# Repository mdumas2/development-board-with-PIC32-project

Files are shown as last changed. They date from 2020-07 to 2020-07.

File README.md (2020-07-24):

# PCB project of our development board utilizing PIC32
***
## SCHEMATICS
schematic
## 2D
PCB 2D
## 3D
PCB 3D
## ISSUES
issues
# Code of our development board utilizing PIC32
***
## STATE MACHINE
Maquina de estado
## UML DIAGRAM
UML
## Bluetooth App
app
## VS code App
pc program

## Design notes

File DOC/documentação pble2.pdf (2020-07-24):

## PBLE02 - Aprendizagem baseada em projeto

Documentação Final

Guilherme F. da Silva 2017011836

Mateus Dumas Lima 2017017965

Windson Faria Maia 33213

Itajubá
2019

Sumário

### 1. Introdução

Este projeto faz parte do conteúdo da disciplina PBLE02 (Aprendizagem Baseada em Projetos 2) do curso de Engenharia Eletrônica da UNIFEI (Universidade Federal de Itajubá) e tem por objetivo dar sequência a disciplina PBLE01 que tem por objetivo apresentar o desenvolvimento de produto desde a concepção até a fabricação.

Nessa etapa através da troca de projetos permite um conhecimento de forma pratica de desenvolvimento de produto.

### 2. Projeto

Em PBLE01 o projeto de hardware tinha características gerais:

Item | Descrição
Conector de alimentação | PJ-002A
Tensão de alimentação | 7Vcc a 12Vcc
Microcontrolador | PIC32MM0064GPM048-I/PT
Conversor USB-Serial | FT232RL / MCP2200-I/SO
Reguladores de 3.3V | LD1117S33CTR
Reguladores de 5.0V | LD1117DT50TR
Amplificador operacional | LM358DG
Cristal de 12 MHz | ATS12A
Diodo retificador Schottky | 1N5819HW-7
Conectores USB | 897-43-004-90-000000
Memória E2PROM- | 24LC512-I/SM
Cristal de 32.768 kHz (RTC) | AB38T-32.768KHZ

Tabela 1 - Características gerais do hardware

Com objetivo de trazer os alunos em um ambiente real de desenvolvimento, em PBLE02 os projetos foram trocados de forma aleatória, trazendo um novo desafio e estudar mais a fundo o projeto já feito na disciplina anterior. Recebemos o projeto da equipe 01, as características gerais de ambas as placas é semelhante, salvo algumas diferenças individuais que não interferem na realização do objetivo para o qual foram projetadas. Seguem nos próximos tópicos os detalhes de cada subcircuito deste projeto, juntamente com os pré-requisitos de cada um deles.

### 2.1 Alimentação

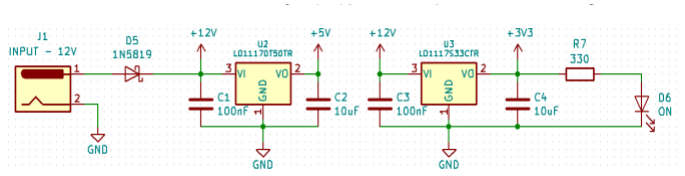
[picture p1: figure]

Figura 1 subcircuito de alimentação

O grupo optou por utilizar os reguladores em paralelo, a fim de evitar que a corrente consumida pelo regulador de 3,3V não afetasse o de 5V. O circuito também possui um diodo schottky de proteção para evitar corrente reversa, assim como um LED de sinalização (D6) para avisar quando a PCI estiver ligada.

### 2.2 Microcontrolador

Como | requisito, | foi | empregado | o | PIC32MM0064GPM048-I/PT. | Tal
microprocessador deve operar com clock interno, possuir quatro diodos emissores de luz para sinalizações diversas e botão de reinício por meio de uma chave táctil de quatro terminais e do tipo normalmente aberta. O reset da placa foi feito para operar por uma chave táctil de quatro terminais. O debounce feito por software.

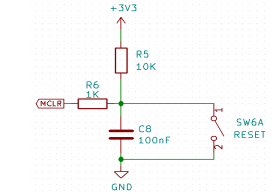
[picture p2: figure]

Figura 2 Circuito de reset.

Figura 3 Subcircuito do microcontrolador

### 2.2 Comunicação

Foi empregado um conversor USB-serial devidamente integrado ao periférico de comunicação UART do microcontrolador com configuração autoalimentada. Para tanto, foi implementado dois tipos de conversores, FT232 e MCP2200-I/SO, de modo que apenas um é ativado para efetuar a comunicação.

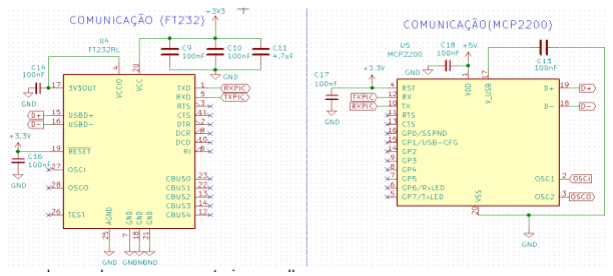
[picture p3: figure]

Figura 5 – Conversores USB-serial

Além disso, utilizou-se 2 conectores USB, no qual o primeiro se conectaria diretamente ao micro utilizando sua comunicação nativa, enquanto o outro seguiria em paralelo tanto para o FT232 quanto para o MCP2200.

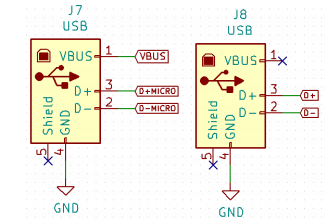
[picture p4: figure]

Figura 6 Conectores USB.

### 2.3 Comunicação

Um dos periféricos implementado é o display LCD 16x2, modelo JHD162A, conectado a uma barra de conexão.

Figura 7 Display LCD

A placa possui um teclado de cinco teclas desenvolvido por meio de chaves tácteis de quatro terminais cada, sendo lido através de uma estrutura de divisor resistivo numa entrada analógica.

Figura 8 Teclado com entrada analógica.

Para a programação do microcontrolador por meio do ICSP, foi utilizado uma barra de conexão de 6 pinos, conforme figura a seguir.

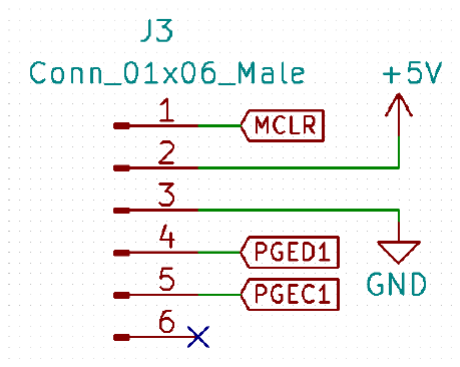
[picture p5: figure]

Figura 9 Conexão ICSP

Por último, foi implementado uma memória serial com comunicação no padrão I2C.

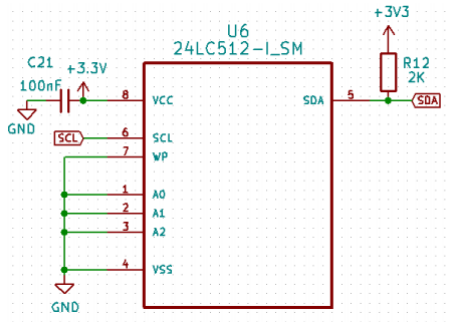
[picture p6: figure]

Figura 10 Memória serial

### 2.4 Interface

Como requisito, a placa possui uma barra de conexão para 4 sinais digitais.

Figura 11 – Conexão sinais digitais

Duas entradas analógicas de 0 à 5V com circuitos de buffer. Como o microcontrolador foi desenvolvido para ler sinais de até 3,3V, foi utilizado um divisor de tensão para atenuação.

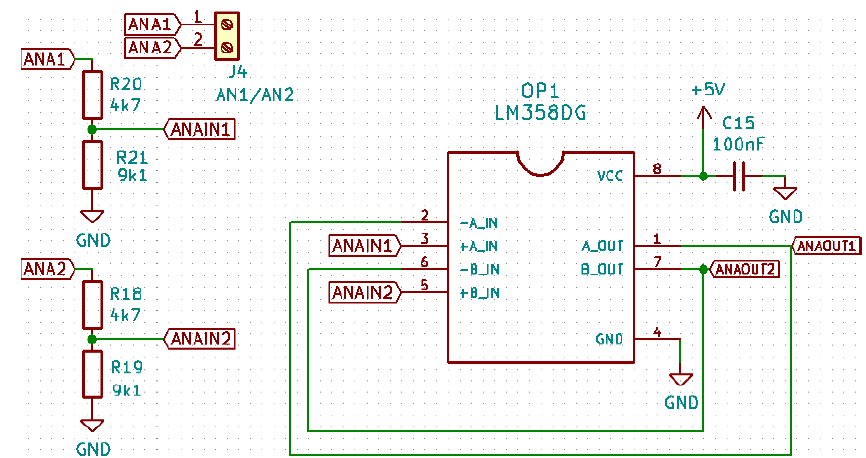
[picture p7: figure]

Figura 12 – Entrada analógica com buffer.

Outra entrada analógica deve ser proveniente de um potenciômetro. Além disso, no mesmo amplificador operacional, está conectado uma saída PWM do microcontrolador utilizando um filtro passa baixa de 2ª ordem (40db/dec) com 1 década a menos de frequência de corte que a frequência do PWM, de modo que a tensão de saída varie de 0 a 5V.

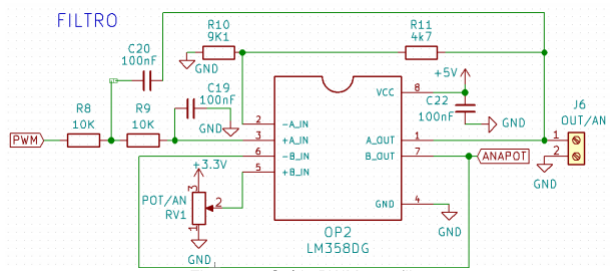
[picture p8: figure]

Figura 13 Saída PWM com filtro.

Os valores das resistências e capacitores utilizados no filtro se deu por meio da calculadora online desenvolvida por Okawa, que possui diversas informações sobre filtros ativos e passivos, além de uma interface que auxilia na realização do cálculo de acordo com os parâmetros desejados.
Além do barramento digital, foi implementado uma barra de conexão 2x4 para 4 pares de sinais de alimentação, dois como sinal de 3,3V e dois de 5V, ambos com um terra associado.

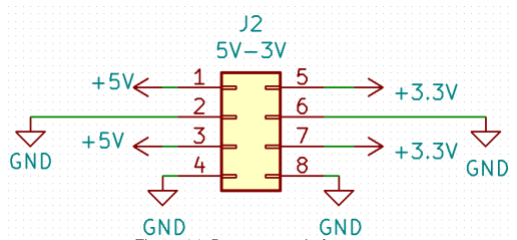
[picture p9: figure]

Figura 14 Barramento de força.

O último item da interface se refere à barra de expansão que emprega todos os pinos do microcontrolador que não sejam alocados pelos demais requisitos de desenvolvimento.

Figura 15 – Barra de extensão.

### 3. Montagem do circuito impresso e levantamento de erros

Grande parte dos alunos inscritos na disciplina PBLE01 tem seu primeiro contato com um ambiente real de desenvolvimento de produtos eletrônicos, contemplando desde a concepção do projeto e fabricação do hardware ao desenvolvimento do software embarcado, portanto, é previsível que os projetos contenham problemas e que os projetistas cometam alguns erros. Visando detectar erros estimular a resolução de tais problemas foram entregues três versões de hardware (VH1,VH2 E VH3) e software (SW1,SW2,SW3) durante a fase de desenvolvimento, corrigidas e revisadas por outras equipes em primeira instancia e posteriormente por técnicos do IESTI e pelo professor do componente curricular.

Contudo, é comum que alguns problemas só sejam detectados durante a fase de montagem , a seguir apresentaremos a montagem do circuito impresso bem como os defeitos observados e a decisão tomada pela nossa equipe 08 com objetivo de encontrar possíveis soluções.

Nesta atividade cada subcircuito foi tratado separadamente em um espaço de uma semana para cada montagem, onde cada qual demandava uma certa metodologia para verificação de possíveis problemas ou equívocos a fim de garantir a segurança dos componentes que seriam usados além do bom funcionamento do sistema como um todo. Usaram-se como ambientes para a execução destas tarefas o laboratório de produção de placas de circuito impresso e a sala da equipe de projetos especiais Uairrior, ambas localizadas na Unifei.

3.1Primeiro subcircuito: Alimentação

Para a verificação de que este subcircuito estava de fato funcionando de modo seguro seguiu-se a seguinte metodologia, exatamente nesta ordem:

. Verificaram-se se as conexões das trilhas referentes ao subcircuito estavam contínuas, por meio de um multímetro.

. Inspecionou-se se os footprints coincidiam com as conexões de cada componente na placa.

. Visto que não foram encontrados quaisquer erros nos dois primeiros passos, pôde-se soldar os componentes.

. Testou-se se havia curtos circuitos entre Vcc e Gnd

. Como não houve nenhuma sinalização de curto circuito, a placa foi energizada com uma fonte de 12 V, verificando em seguida os níveis de tensão nas saídas dos reguladores de 5 e 3.3 V conferindo se de fato estavam de acordo com o esperado.

. Por fim, após o último passo ter sido confirmado bem-sucedido verificou-se que o led da alimentação estava de fato aceso, comprovando que o subcircuito estava funcionando.

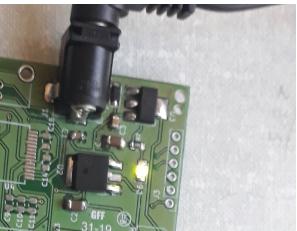
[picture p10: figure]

Figura 16 Circuito de Alimentação

### 3.2 Segundo subcircuito: Microprocessador

Depois da verificação das conexões das trilhas relativas ao micro aonde não foram encontrados erros além da garantia que estava chegando uma tensão de 3.3 V e não de 5 V verificou-se no esquemático que o capacitor conectado ao pino Vcap (C5) possuía um valor menor (100nF) do que o indicado pelo datasheet (10uF).

Figura 17 - Capacitor do pino Vcap indicado pelo datasheet do microprocessador

Trocou-se um capacitor pelo outro e ainda que este fosse um pouco maior do que o primeiro ao medir a continuidade comprovou-se que não havia mudado nada.

Além disso, na conexão do micro com o conector onde seria colocado o PicKit notou-se que a tensão que este seria alimentado era de 5 V o que era incorreto já que este deve possuir a mesma tensão do micro que é de 3.3 V. A correção foi feita cortando a trilha de 5 V então conectada ao conector e com um pequeno jumper ligar uma trilha de 3.3 V próxima ao pino Vdd do conector a este.

Então foi feito um programa no software MPLAB cujo objetivo era acender os 4 leds da placa. Entretanto, ao rodar o programa não se verificou quaisquer mudanças no estado dos leds indicando o não funcionamento do circuito como um todo.

Partiu-se então a uma varredura com o objetivo de identificar possíveis erros e o que foi descoberto era que o problema estava na conexão do botão do reset(SW6) que originalmente estava em curto fazendo com que o microcontrolador estivesse resetado durante todo o tempo. O curto foi originado pela má conexão do componente na PCB pois estava posto do lado contrário ao correto. Assim, para encaixa-lo na posição correta foi necessário o uso de um alicate para entortar as suas “pernas” de modo que coubesse nos pads. Esse processo fez com que após o conserto o botão tivesse um aspecto meio torto, porém com o multímetro comprovou-se que não havia mais curto.

Com isso testou-se novamente o mesmo programa citado anteriormente onde desta vez funcionou sem problemas levando ao fato que o micro estava operando com sucesso.

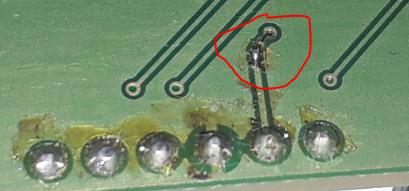
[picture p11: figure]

Figura 18 - figura do conserto do problema da tensão no conector do pickit3, onde conectou-se 3.3V no Vdd

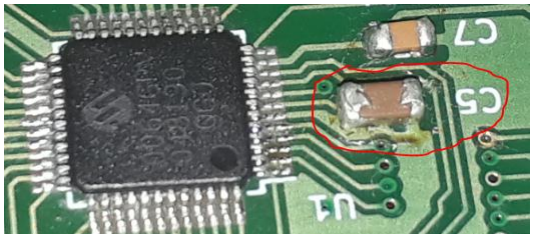
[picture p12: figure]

Figura 19 - Capacitor depois da troca já soldado

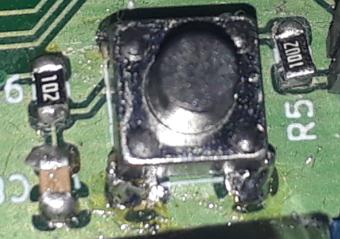
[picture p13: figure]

Figura 20 - Botão do Reset depois de soldado

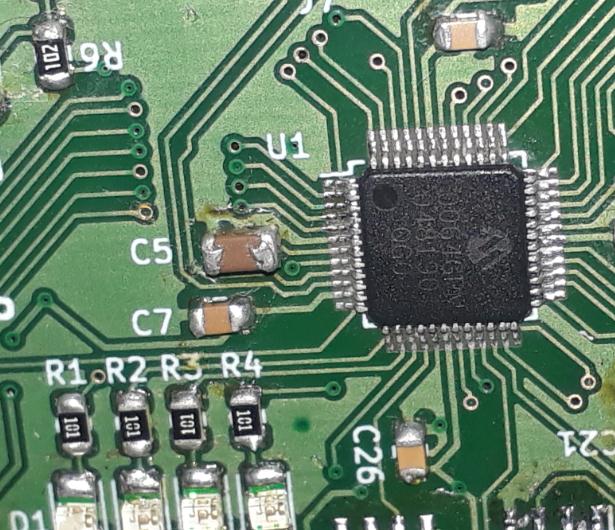
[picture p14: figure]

Figura 21 - Circuito do microcontrolador

### 3.3 Terceiro subcircuito: Comunicação

Primeiramente, foi estabelecido pelo professor de que se usaria o componente MCP2200 para o subcircuito ao invés do FT232. Entretanto, notou-se claramente de que o modo que foi feito o esquemático deste componente havia alguns erros com o que está proposto no datasheet oficial referente ao modo de funcionamento proposto que era o autoalimentado.

Figura 22 - Modo auto-alimentado do MCP2200 indicado pelo datasheet

Os pontos que estavam em desacordo eram que o pino Vdd no esquemático estava sendo alimentado por 5 V enquanto que no esquemático o valor especificado era de 3.3V. Além disso o pino V_USB estava conectado ao terra junto com um capacitor ainda que no datasheet constava-se de que ele deveria estar conectado junto ao Vdd com 3.3V. Depois dessas correções os componentes do subcircuito foram soldados e então por meio de um cabo usb compatível com o conector da placa foi feita a verificação se o driver do MCP2200 era reconhecido pelo computador através da entrada serial localizada em uma porta COM do dispositivo. Entretanto, isso não aconteceu acusando assim o não funcionamento do subcircuito.

A partir daí, suspeitou-se que o problema poderia estar residido no fato de não haver um resistor de pull-up na conexão do pino do r. Então inseriu-se um resistor de 10k para justamente realizar a função de pull-up, porém ao realizar a conexão com o computador notou-se novamente que não havia quaisquer notificações de instalação de driver. Após isso retirou-se o capacitor que estava conectado ao reset julgando que não havia razão para sua presença ali. Mais uma vez foi feita a conexão com o computador mas não houve novamente qualquer sinal de vida do componente.

Por fim, ao consultar uma outra equipe cujo subcircuito estava funcionando implementou-se as seguintes mudanças: conectou-se diretamente o pino do reset a 3.3 V, além de cortar qualquer conexão do pino V_USB, além de jogar o pino de Vss diretamente no Gnd, retirando de uso o capacitor C13 mantendo Vdd alimentado por 3.3V. Realizaram-se essas mudanças depois da troca do mcp2200 por um novo do mesmo modelo por suspeitar de que o antigo já estivesse queimado. Por fim, conectando a placa com o computador verificou-se a instalação do driver significando o funcionamento do componente e suas conexões, o que foi confirmado ao realizar um código de receber e enviar caracteres através de um software de terminal serial que funcionou perfeitamente.

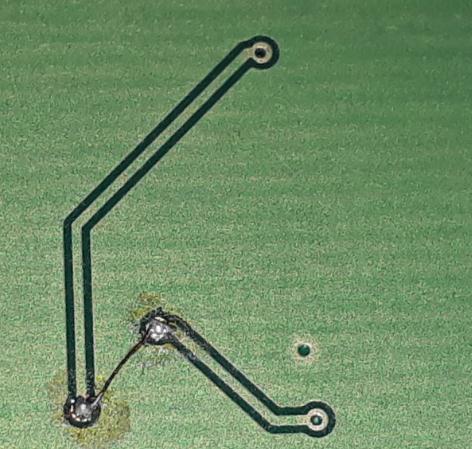
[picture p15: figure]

Figura 23 - Solução do problema relacionado à tensão conectado ao pino de Vdd que era de 5V e passou a ser de 3.3V

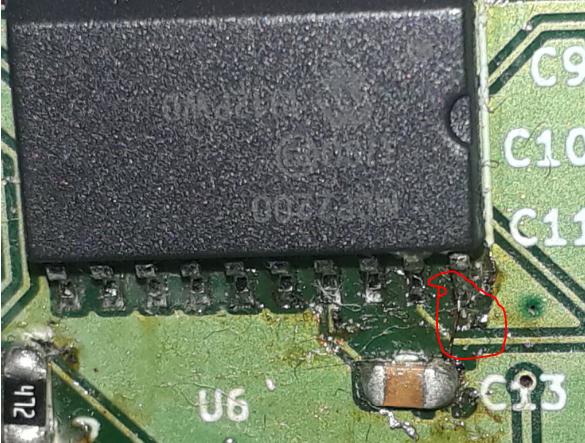
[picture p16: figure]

Figura 24 - corte da conexão do pino Vss com o capacitor C13

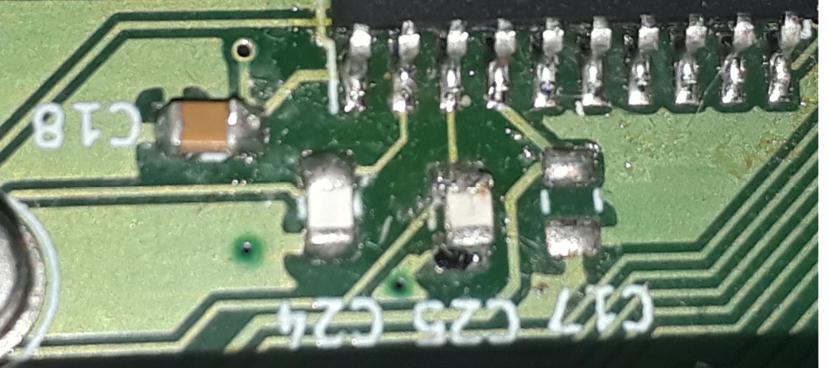
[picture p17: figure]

Figura 25 - Retirada do capacitor C17, anteriormente conectado com o pino de reset

### 3.4 Quarto subcircuito: Periféricos

Com respeito ao LCD, verificou-se que o pino 3 do lcd onde conecta-se o pino de saída do potenciômetro tinha no meio da conexão uma passagem por um ponto de Gnd em um furo no canto lateral da placa. Isso impossibilitava o funcionamento do potenciômetro e consequentemente o controle de contraste da tela do componente. Com isso, cortou-se esta trilha e por meio de um jumper foi realizada a conexão dos dois pinos em questão externamente.

Com relação ao teclado, foi identificado o mesmo erro já ocorrente com o botão do reset relacionado ao fato do botão estar posto no footprint de forma invertida e com isso formava-se um curto. Este fato foi observado em cada um dos 5 botões do teclado. A solução realizada foi a mesma, entortando-os de modo que coubessem na posição correta individualmente.

Já no circuito da memória, notou-se inicialmente de que não havia um resistor de pull-up para o pino SCL, o que configurava um equívoco já que desta forma o componente não poderia operar de forma satisfatória. Além disso, o resistor colocado como pull-up do pino SDA|(2kΩ), não constava na lista de compras, ou seja, estava indisponível para uso.

A solução encontrada foi inserir um resistor externo na placa conectado com o capacitor C21 de modo que fosse provido a ele 3.3 V. Foi escolhido o valor de 4k7 Ω tanto para esse resistor externo quanto para o que já estava conectado ao pino SDA| já que garantia um valor seguro para o funcionamento de ambos os resistores como pull-up dada a tensão aplicada neles.

Implementando essas soluções, ambos os circuitos funcionaram sem problemas.

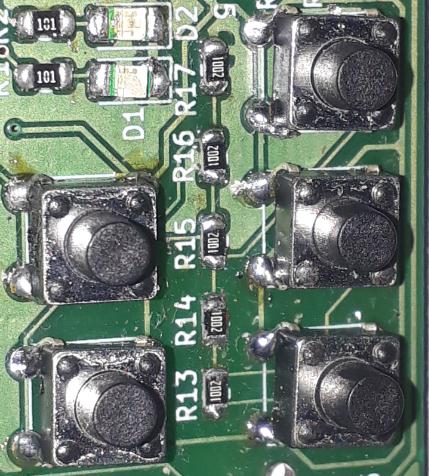
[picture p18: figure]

Figura 26 - Botões do circuito do teclado soldados

Figura 1- solução do problema no LCD

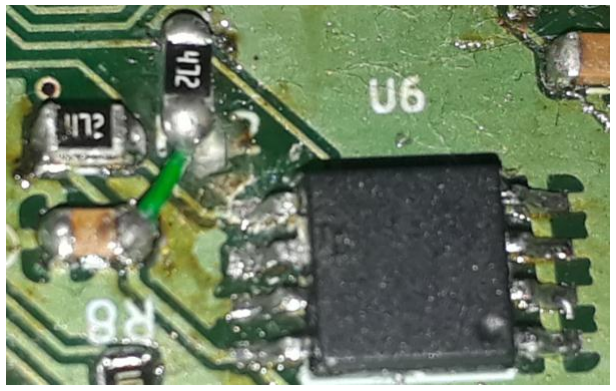
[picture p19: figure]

Figura 2- Correção do problema no circuito da memória, onde um novo resistor foi inserido e conectado junto ao capacitor C21

### 3.5 Quinto subcircuito: Interface

Neste subcircuito foi encontrado somente um erro. No filtro passa baixa, esqueceu-se de realizar a conexão do capacitor C20 com o resistor R9 no esquemático e consequentemente no PCB também. Bastou que na hora da solda ligasse ambos os componentes por meio do estanho.

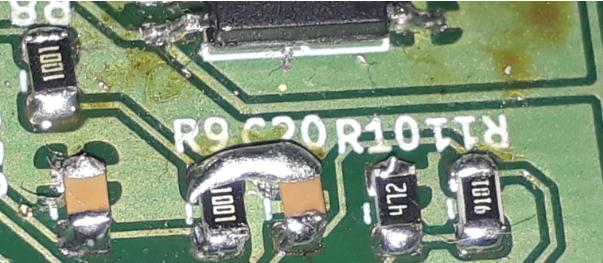
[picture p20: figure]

Figura 29 - conexão externa do resistor R9 com o capacitor C20

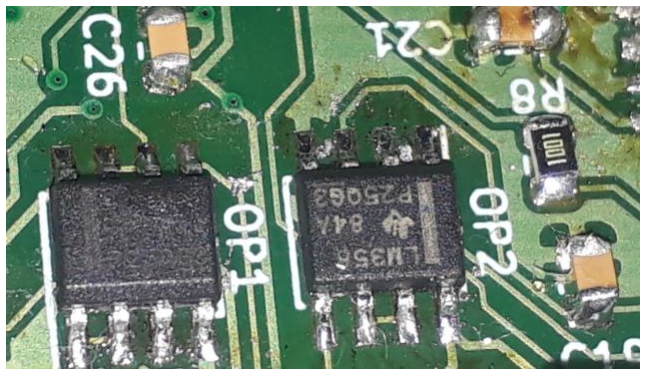
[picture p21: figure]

Figura 30 - Os ampop's do circuito de interface soldados

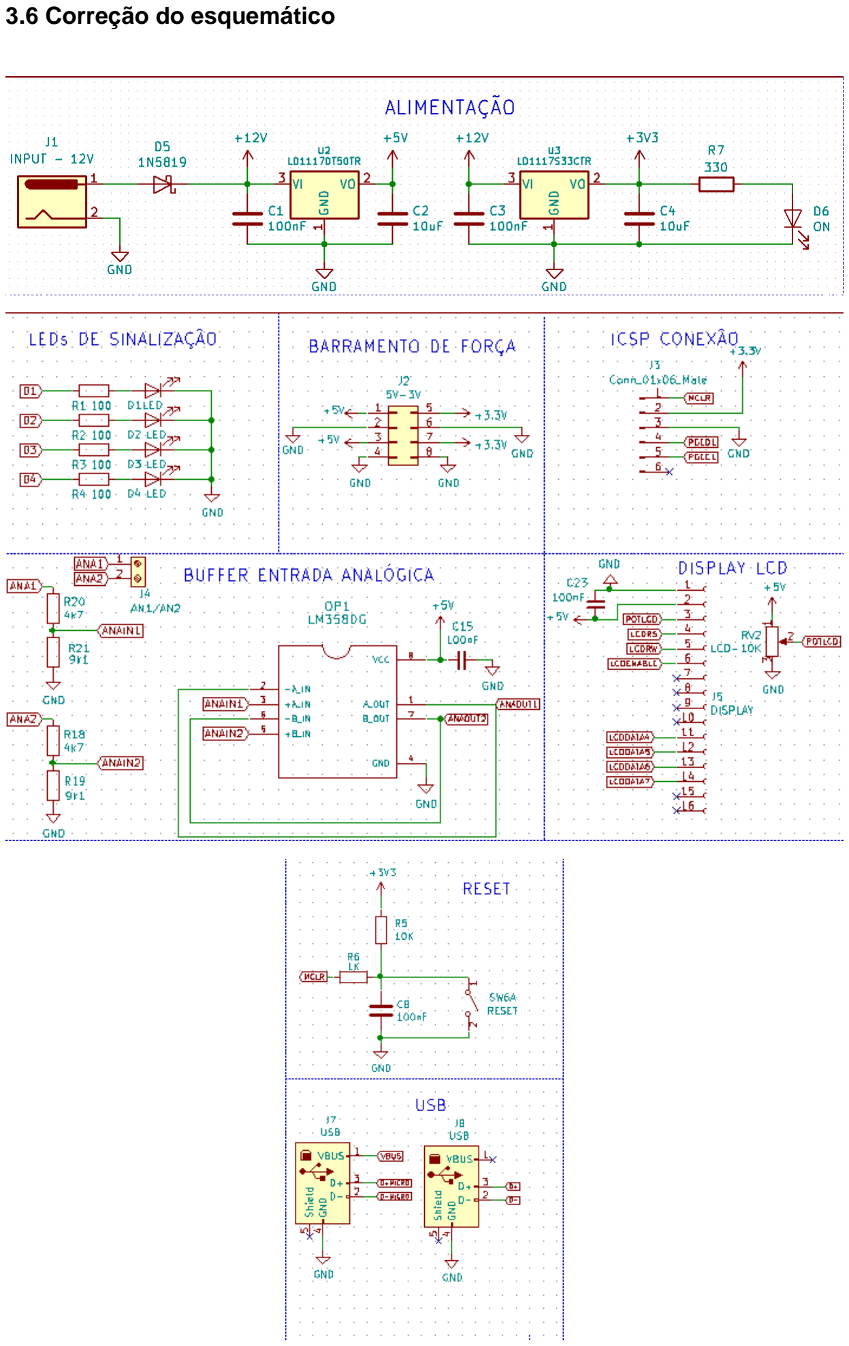
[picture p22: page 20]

### 3.6 Correção do esquemático

Figura 31 - Esquemático corrigido

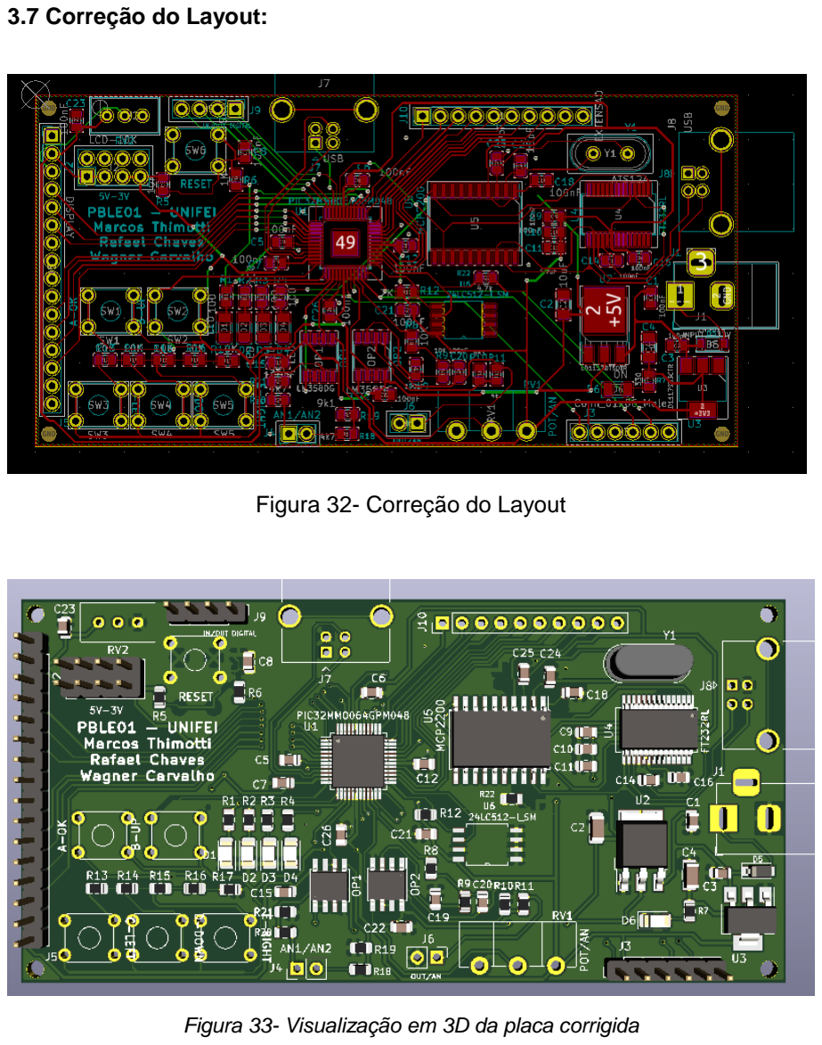
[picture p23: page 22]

### 3.7 Correção do Layout:

Figura 32- Correção do Layout

Figura 33- Visualização em 3D da placa corrigida

### 4. LISTA DE MATERIAIS E ANÁLISE DE CUSTOS

Com o intuito de facilitar a consulta e consequentemente a compra dos

componentes eletrônicos, foi feito um levantamento de todos os componentes

utilizados neste projeto e seu respectivo modelo de acordo com a tabela

abaixo. Além disso, foi pesquisado os preços cada tipo de componente na

distribuidora Mouser Electronics.

Tabela 2 – Lista de materiais.

Descrição | Quantidade | Encapsulamento/modelo | Valor | Preço (US$)
Capacitor Cerâmico | 18 | 0805 | 100nF | 0.81
Capacitor de Tântalo | 3 | 1206 (F931C106KAA) | 10uF | 1.80
Capacitor Cerâmico | 2 | 0805 | 10pF | 0.72
Capacitor Cerâmico | 1 | 0805 | 4,7uF | 0.54
Resistor | 4 | 0805 | 100Ω | 0.10
Resistor | 1 | 0805 | 330Ω | 0.10
Resistor | 1 | 0805 | 1kΩ | 0.10
Resistor | 5 | 0805 | 4,7kΩ | 0.50
Resistor | 3 | 0805 | 9,1kΩ | 0.30
Resistor | 8 | 0805 | 10kΩ | 0.80
Potenciômetro | 1 | P160KN-0QD15B10K | 10kΩ | 0.76
Potenciômetro | 1 | 3296W-1-103RLF | 10kΩ | 3.93
LED | 5 | LTST-C150GKT | | 1.60
Diodo schottky | 1 | 1N5819HW-7 | | 0.44
Chave táctil | 6 | 1825910-6 | | 0.60
Conector jack J4 | 1 | PJ-002A | | 0.60
Conector | 2 | PPTC021LFBN-RC | 1x02 | 0.64
Conector | 1 | PPTC041LFBN-RC | 1x04 | 0.45
Conector | 1 | PPTC061LFBN-RC | 1x06 | 0.52
Conector | 1 | PPTC101LFBN-RC | 1x10 | 0.65
Conector | 1 | PPTC161LFBN-RC | 1x16 | 0.98
Conector | 1 | PPTC042LFBN-RC | 2x04 | 0.67
Conector USB | 2 | 897-43-004-90-000000 | | 2.78
Cristal | 1 | ATS12A | 12MHz | 0.36
Amplificador Operacional | 2 | LM358DG | | 0.92
Regulador de Tensão | 1 | LD1117S33CTR | | 0.40
Regulador de Tensão | 1 | LD1117DT50TR | | 0.47
Conversor USB-Serial | 1 | FT232RL | | 4.50
Conversor USB-Serial | 1 | MCP2200-I/SO | | 1.99

Memória E2PROM | 1 | 24LC512-I/SM | | 1.33
LCD | 1 | JHD162A( | | 9,40
Microcontrolador | 1 | PIC32MM0064GPM048-I/PT – TQFP48 | | 1.99
| | | Total | 41,75
| | | Total(R$) | 176.11

Além disso, o custo material e físico para a solda e montagem dos componentes foi avaliado em 50R$. Com isso, o projeto como um todo teve um custo de 226,11R$.

### 5. Manutenção e descarte

### 5.1 Manutenção

A primeira coisa a ser verificada para garantir que a placa esteja funcionando é

que o led de alimentação esteja aceso ao alimentar a placa com uma tensão de

até 12 V. Caso isso não ocorra verifique primeiramente se realmente a tensão

é menor ou igual a 12 V. Se é, provavelmente o problema está em alguns dos

reguladores de tensão que possa estar queimado. Para se certificar disso meça

com o voltímetro a tensão nos pinos de entrada e saída de cada um dos

reguladores. A posição desses pinos pode ser vista através do esquemático do

projeto. Por exemplo, a tensão em cima do pino de entrada do regulador de 5V

deve ser igual a tensão colocada no JACK-DC enquanto que a tensão de saída

deve ser 5V. Caso não seja, provavelmente o regulador está queimado e

necessita ser trocado. O mesmo se aplica ao regulador de 3.3 V, com a

diferença que a tensão de saída deste deve estar na casa de 3.3V.

Após isso, quando algum problema ocorrer com qualquer periférico da placa

verifique antes de tudo se a tensão que chega sobre ele é a esperada (5V ou

3.3V) e que não há problemas com o GND (verifique a continuidade). Se estes

fatores estiverem de acordo com o esperado, pode ser que o problema esteja

no microcontrolador e não no periférico.

Para descobrir possíveis problemas no micro, primeiramente verifique se a

tensão que chega para alimenta-lo é 3.3 V e não 5 V. Em caso positivo,

verifique em seguida se o botão de reset está funcionando, e não em curto

medindo a continuidade entre seus pinos. Repita esse processo com os demais

botões do teclado. Se estiverem todos funcionando, pegue o pino de saída do

micro que está ligado ao periférico com problema e conecte-o ao osciloscópio.

Grave o código desejado e alimente a placa. Verifique então se há de fato um

sinal sendo enviado pelo microcontrolador e se está de acordo com o que era

para ser feito por ele. Se era, o problema está provavelmente sobre o periférico

e não sobre o micro e o periférico precisa ser trocado. Em caso negativo, a justificativa se inverte. Em situações onde o microcontrolador recebe os dados

ao invés de envia-los o procedimento também pode ser aplicado.

Em relação à problemas com o gravador PICKIT3 verifique que o pino de

tensão de entrada deste é alimentada com 3.3 V e não com 5 V, além de que

ele está conectado na posição correta, exatamente como mostra a imagem a

seguir:

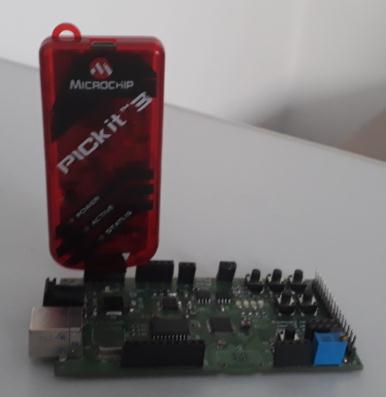
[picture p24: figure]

Figura 34-Colocação correta do PICKIT 3

### 5.2 Descarte

O produto possui muitos metais pesados pesados como mercúrio,que pode contaminar o solo e aguas além de camadas de cobre e silício,materiais como plástico podem demorar para se decompor na natureza.

Pensando nisso é aconselhável em caso de descarte,que o procedimento seja em postos de coleta de lixo eletrônico mais próximo.

6.Bibliografia
Datasheets dos componentes

https://www.sparkfun.com/datasheets/IC/FT232R_v104.pdf

https://ww1.microchip.com/downloads/en/DeviceDoc/22228A.pdf

http://ww1.microchip.com/downloads/en/DeviceDoc/60001387c.pdf

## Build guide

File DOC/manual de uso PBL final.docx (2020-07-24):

MANUAL DE USO DO SOFTWARE DA PLACA

Utilizando-se da placa de desenvolvimento, configurou-se o teclado da seguinte forma para o funcionamento do produto:

Tecla | Função
1 | Enter/Confirmar
2 | Back/Voltar
3 | Next/Direita
4 | Up/Cima
5 | Down/Baixo

Onde a disposição das teclas na placa em questão é mostrada abaixo:

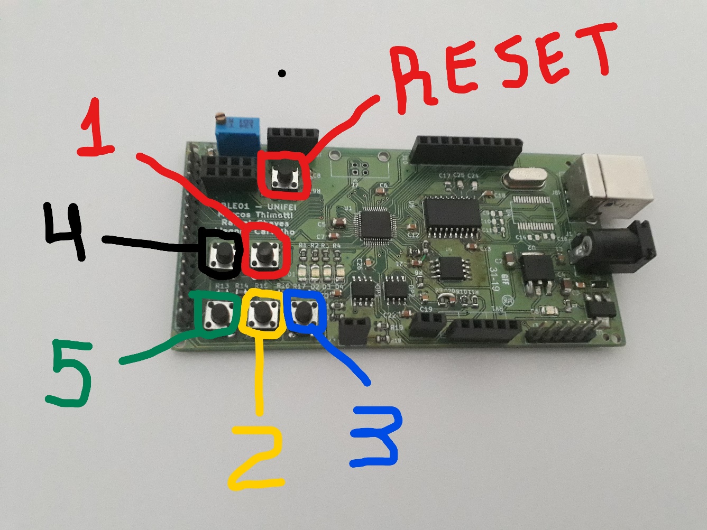
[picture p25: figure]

Logo após a ligação do produto é apresentado o menu de configuração, em que há 4 possíveis seleções, as quais estão enumeradas em ordem crescente na seguinte disposição: 1-Display Sensor, 2-Alterar Idioma, 3-Configura Valor, 4-Display DT/HR e 5-Configura DT/HR, onde a passagem de uma seção para a outra é feita por meio do botão 3(NEXT), que é indicado por uma setinha no canto inferior direito no LCD. A explicação da função de cada seção será feita ao longo deste documento.

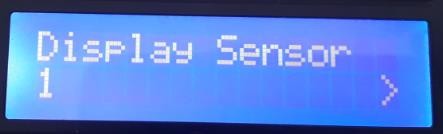
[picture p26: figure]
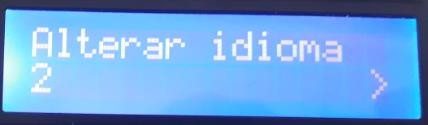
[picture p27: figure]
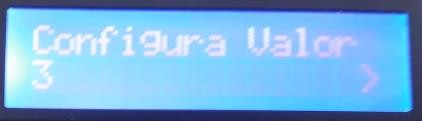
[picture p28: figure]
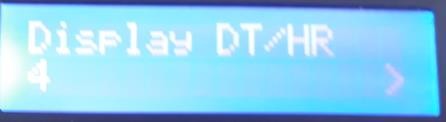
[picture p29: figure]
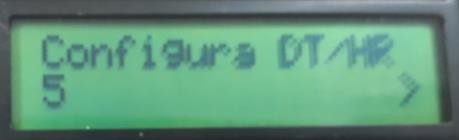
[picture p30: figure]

Como pode se notar, os nomes das seções estão na parte superior da tela, enquanto na linha inferior são mostrados a posição de cada seção no que diz respeito ao menu de configuração para que o usuário não acabe se perdendo quando vai mudando com os botões além da setinha indicando a direção da mudança de uma seção para a outra. Quando apertado o botão NEXT na quarta seção, o menu volta para a primeira Display Sensor.

Agora que foi apresentado este primeiro menu, a opção para a entrada em uma seção é feita através do botão 1(ENTER), e uma vez dentro deste sub-menu, caso o usuário queira voltar para o menu de configuração basta apertar o botão 2(BACK).

Apertando ENTER na seção Display Sensor, se terá a seguinte disposição:

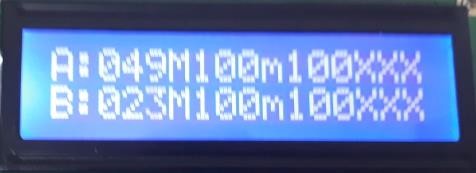
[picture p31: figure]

Neste sub-menu, como o próprio nome diz, é mostrado no LCD os valores correspondentes aos dois sensores A e B (1 e 2) disponíveis para medição na placa.

O significado para a ordem destes valores é a seguinte:

Os 3 primeiros números (na foto, pegando o sensor A de exemplo, possui um valor de

049) correspondem a medição analógica, feita por meio do potenciômetro e portanto, varia conforme o usuário mexa neste componente.

Logo em frente é mostrado os valores configurados como máximo e mínimo, cujo processo é feito em outra seção do programa, que correspondem na ordem: M (máximo e os 3 números seguintes são o valor definido) e m (mínimo, com os 3 números seguintes sendo o valor definido pelo usuário). Os valores de X subsequentes não possuem

quaisquer aplicações. Na foto em questão, os valores que são vistos representam o estado padrão do programa, e como foi explicado anteriormente, são sujeitos a mudança conforme vontade de quem esteja operando a placa.

Apertando o botão 2(BACK), volta-se ao menu de configuração e apertando logo depois o botão 3(NEXT) o programa vai para a seção Alterar Idioma. Para entrar neste sub- menu, da mesma forma explicada anteriormente, basta apertar o botão 1(ENTER).

Uma vez apertado este botão, é mostrado na tela a primeira língua disponível para a escolha, que é a padrão (português).

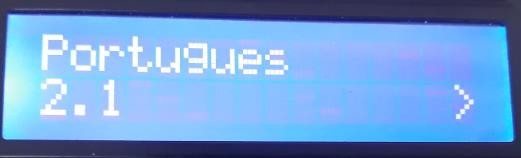
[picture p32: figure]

Conforme mostra a setinha, apertando o botão 3(NEXT), pode-se ver a outra língua disponível para uso, que no caso é o inglês.

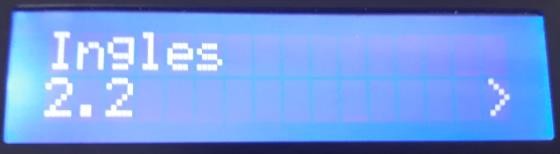
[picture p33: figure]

Caso o usuário queira mudar o idioma, ele deve ir na seção do idioma que não está sendo usado no momento e apertar 1(ENTER). O novo idioma será posto em uso e volta-se para o menu de configuração.

Se ele não quiser mudar, basta apertar 2(BACK), fazendo com que o idioma em uso seja mantido, voltando para o menu de configuração.

Voltando a falar deste menu, indo para a direita (NEXT) chega-se ao menu Configura Valor, cuja função é a possibilidade da alteração, conforme a vontade do usuário, dos valores correspondentes aos sensores além do alarme. Para entrar no sub-menu, aperte A(ENTER).

Com isso, tal qual o menu de configuração geral, é mostrado as subseções disponíveis para escolha, enumeradas. Cada subseção nada mais é do que uma grandeza para ser configurada. A mudança de uma para outra é feita através do botão 3(NEXT). Caso queira-se voltar para o menu de configuração, aperte 2(BACK).

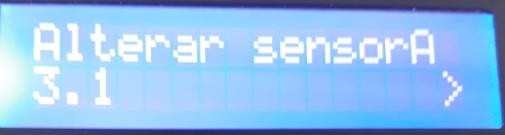
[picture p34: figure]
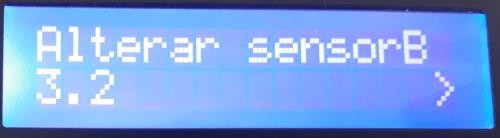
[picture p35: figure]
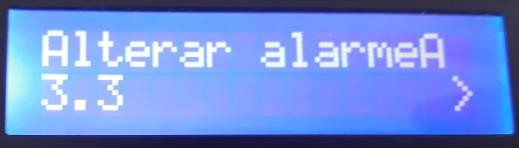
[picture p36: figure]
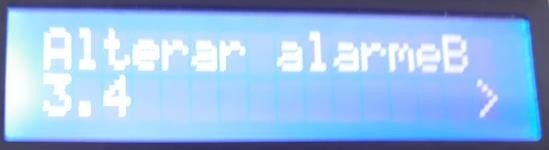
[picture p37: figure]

Apertando 1 (ENTER) na subseção 3.1 (Alterar sensorA) tem-se a seguinte disposição no programa:

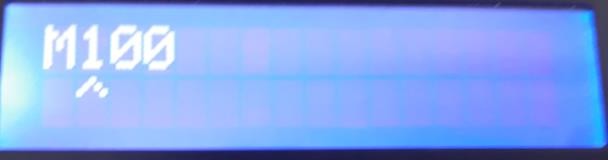
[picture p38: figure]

Ou seja, é dado o valor máximo do sensorA para ser configurado.

Para alterar este valor, usa-se dos botões 3(NEXT), 4(CIMA) e 5(BAIXO). O botão 3 serve para alterar a posição do cursor, conforme queira-se mudar a centena, dezena ou unidade do valor. Já os botões 4(CIMA) e 5(BAIXO), conforme seus respectivos nomes servem para aumentar ou diminuir em 1 o número em que o cursor esteja posicionado. Caso, estando o número igual a 9, ao apertar o botão correspondente a CIMA, o número passará a valer 0. O caso contrário, número igual a 0, e o subsequente pressionamento do botão correspondente a BAIXO, não resulta em nenhuma mudança, pois foi programado para que não houvessem mundaças nesse tipo de situação e o valor permanece em 0.

O uso do cursor é extremamente útil, já que possibilita o usuário a mudar o valor geral de máximo de 0 a 999 com facilidade.

Uma vez que o valor esteja configurado com a vontade do operador, aperte 1(ENTER) para salvá-lo. Ao fazer isso, a tela irá para a disposição mostrada abaixo:

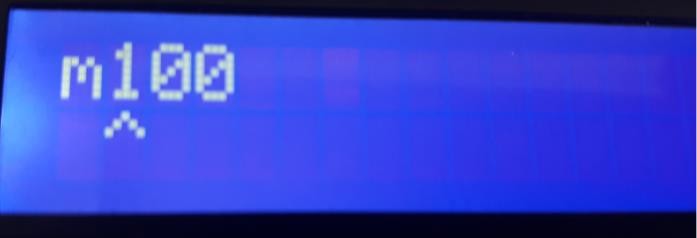
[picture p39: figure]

Que é justamente o display de configuração do valor mínimo do sensor A, cuja alteração do valor é exatamente a mesma explicada para o valor máximo. Quando o usuário já estiver certo quanto a este valor, aperta-se A(ENTER) para salvá-lo. Depois, de fazer isso o programa irá comparar o valor mínimo com o máximo definidos pelo operador. Caso o valor mínimo seja maior que o máximo, é mostrado a seguinte mensagem de erro:

Para sair desta tela, aperta-se 1(ENTER) e o programa vá para o sub-menu Display Sensor, com os valores anteriores a última configuração feita pelo usuário, já que esta foi inválida.

Se o valor mínimo for menor que o máximo é mostrado a mensagem:

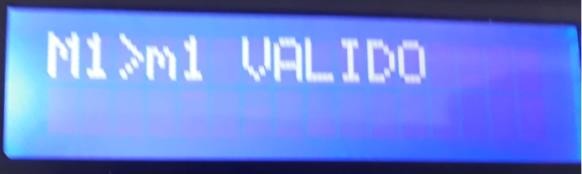
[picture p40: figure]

Para sair desta tela, aperte 1(ENTER) fazendo com que se mostre o sub-menu Display Sensor, desta vez com os valores atualizados conforme a última alteração do operador, na primeira linha.

Em relação a subseção 3.2 (Alterar sensor 2), o procedimento para alteração dos valores de máximo e mínimo são iguais ao da última subseção explicado anteriormente, sendo a única diferença o fato de que o valor salvo( caso a seleção de máximo e mínimo seja válida) será mostrado no sub-menu Display Sensor na segunda linha no LCD.

No que diz respeito a subseção 3.3(Alterar AlarmeA), ao apertar 1(ENTER), é mostrado na tela a seguinte disposição:

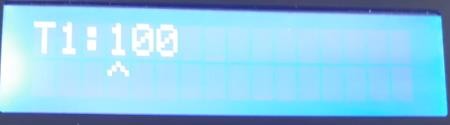
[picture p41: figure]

Através desta subseção, é possível alterar o valor do tempo de verificação do alarme em segundos, ou seja, o intervado de tempo em que ele é medido e comparado com os valores fornecidos pelos sensores.

Ele é configura por meio dos botões 3(DIREITA), 4(CIMA) e 5(BAIXO), onde o 3 movimenta o cursor e 4 e 5 alteram o valor do número indicado pelo cursor em 1 para cima(Botão 4) ou para baixo (Botão5).

Depois de ter o valor configurado, aperte 1(ENTER) para que salve a mudança feita. Com isso, o programa volta para a subseção 3.3(Alterar AlarmeA). Apertando 2(BACK) fará com que o programa também volte para a subseção 3.3.

Em relação à subseção 3.4(Alterar AlarmeB), o método para alteração do valor do AlarmeB desejado é similar ao realizado na subseção anterior.

A seção 4 Display DT/HR que se situa no menu de configuração mostra na tela a data e a hora do dia. Para entrar no sub-menu e desta forma, poder ver a data e a hora, aperta-se 1(ENTER). Com isso, é mostrado a seguinte imagem:

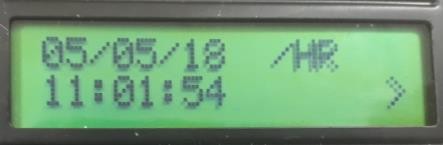
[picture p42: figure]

Onde é mostrado os valores na linha de cima a data e na de baixo a hora. Para voltar para a seção 4(Display DT/HR), basta apertar o botão 2(BACK).

A última seção disponível no menu de configuração é a: 5-Configura DT/HR, na qual o usuário tem a disponibilidade de alterar o valor da data e hora do programa conforme sua vontade. Estando nessa seção, ao apertar o botão 1(ENTER), entra-se na subseção 5.1- Alterar Data, como é mostrado abaixo:

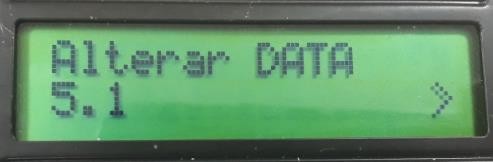
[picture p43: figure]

Nesta posição, o usuário tem três escolhes. Ele pode apertar 1(ENTER) e a partir daí, alterar a data do programa, ou apertar 2(BACK) e voltar para a seção 5(Configura DT/HR) ou apertar 3(NEXT) e ir para a subseção 5.2- Alterar Hora que tem a seguinte representação, cujas escolhas são iguais a da anterior:

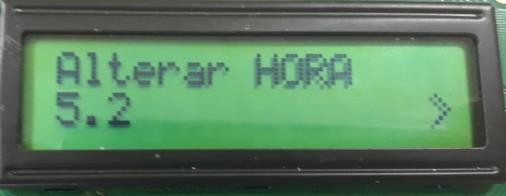
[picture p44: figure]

Tendo uma vez apertado 1(ENTER) na subseção 5.1(Alterar DATA) o operador vai se deparar com a tela abaixo, onde mostra a data padrão na ordem: DD/MM/AA:

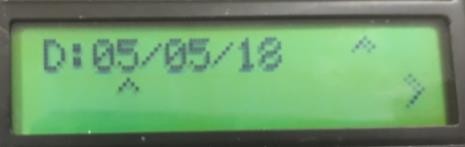
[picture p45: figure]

Para mudar a data do programa, o usuário dispõe do uso dos botões 3(NEXT), 4(CIMA) e 5(BAIXO). O botão 3 serve para movimentar o cursor e, portanto, deixar disponível a mudança tanto do dia quanto do mês e ano. Os botões 4 e 5 servem para aumentar e diminuir respectivamente em 1 o valor do número indicado pelo cursor.

Tendo configurado o valor da data, o usuário pode apertar 1(ENTER) e ir para a subseção 5.2(Config Hora), ou apertar 2(BACK) e voltar para a subseção 5.1(Config Data).

Considerando que ele tenha apertado 1(ENTER), a tela de mudança do valor da hora do programa é a seguinte:

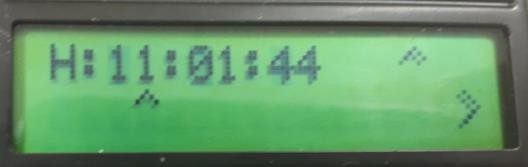
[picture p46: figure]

Onde o procedimento para a alteração dos valores mostrados é exatamente a mesma da data explicada logo acima. Vale lembrar que os valores estão dispostos na ordem: HH/MM/SS.

Tendo configurado o valor da hora, o operador ao apertar 1(ENTER), faz com o programa vá para a subseção 5.1(Config Data). Já se ele apertar 2(BACK), volta-se para a subseção 5.2(Config Hora).

Por fim, caso algum dos alarmes (A ou B) fique ativo, será automaticamente mostrada na tela a notificação deste acontecimento, junto com o valor do alarme(tempo), além da hora em que ocorreu a ativação. As imagens a seguir exemplificam este estado para cada alarme:

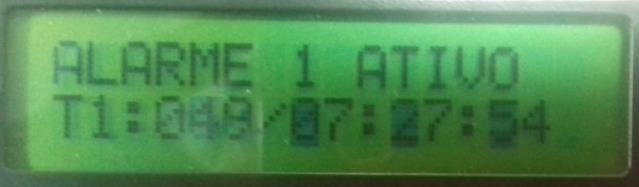
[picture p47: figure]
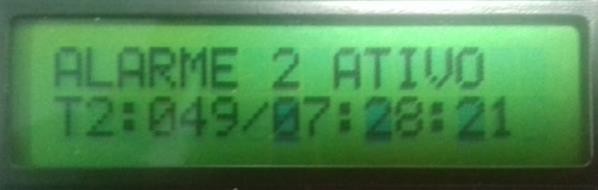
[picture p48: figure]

Para sair desta tela, o usuário deve apertar 1(ENTER) fazendo com o que o programa vá para o display dos sensores.

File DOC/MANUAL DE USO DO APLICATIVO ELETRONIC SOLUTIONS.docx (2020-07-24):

MANUAL DE USO DO APLICATIVO ELETRONIC SOLUTIONS/PC

MENU CONEXÃO:

Antes de tudo, faça a instalação do setup referente ao aplicativo. O arquivo é seguro e livre de vírus e malwares. Depois da instalação você já será apto a utilizar o aplicativo, instalado na pasta desejada. Ao clicar no arquivo .exe o aplicativo será inicializado e abrirá na seguinte seção:

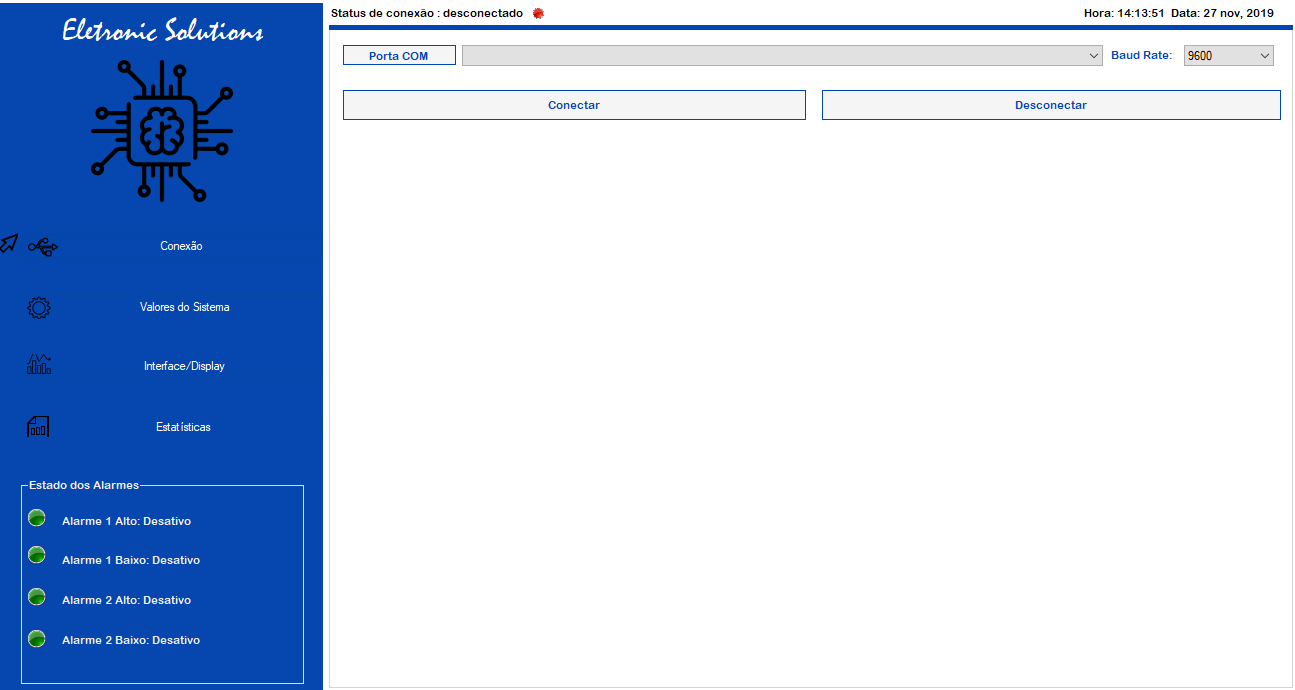
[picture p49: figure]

Esta tela se trata do menu de conexão, cuja função como diz o nome é fazer a conexão entre o seu pc e o microcontrolador que será usado. Como pode se ver, têm-se no total duas informações passíveis de serem mudadas neste menu. A primeira é a “Porta COM”, que se trata em qual terminal do seu pc que foi colocado o cabo usb-serial referente ao microcontrolador. Ou seja, certifique-se que esta conexão já tenha sido feita além de verificar qual Porta COM o cabo foi detectado. Isso pode ser feito indo no menu gerenciador de dispositivos do seu computador.

Para selecionar qual a porta COM vai ser usada como porta serial pelo aplicativo basta clicar no botão “Porta COM”. Ao fazer isso a caixa de texto seguinte a esse botão disponibilizará todas as portas COM aptas a serem usadas no momento. Escolha a porta COM em que foi conectado o cabo USB-serial que também deve estar conectado ao microcontrolador.

Caso você não tenha nenhum cabo usb conectado em quaisquer das portas COM de seu computador o aplicativo acusará um erro.

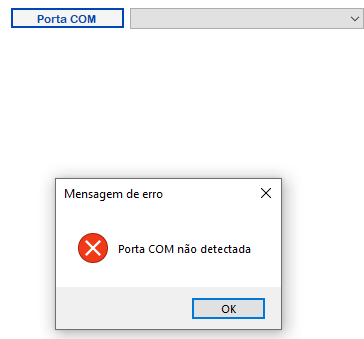
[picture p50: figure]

Uma vez que você já tenha completado sucessivamente este passo, pode-se notar que a caixa de texto ao lado identificado como baud rate possui o valor de 9600 e não é passível de mudança. O motivo para isso é que o microcontrolador usado como padrão possui este baud rate e que a possibilidade de mudança deste parâmetro por meio do aplicativo provocaria problemas em relação a incompatibilidade de transmissão de dados pela porta serial.

Agora, para efetivar a conexão entre o computador e o microcontrolador, clique no botão conectar. Desde que você tenha já definido a Porta COM sucessivamente, a conexão será realizada sem problemas e além disso se mudará o estado do status de conexão, localizado na parte superior da tela que acusará que que o aplicativo está conectado.

Uma vez conectado, não será mais possível mudar pelo aplicativo a Porta COM definida. Caso você tenha se enganado com respeito a ela, terá que clicar no botão desconectar e assim poderá mudar a Porta COM sem preocupação. Se o clique no botão conectar for realizado sem que tenha definido a Porta COM com antecedência o sistema acusará o seguinte erro:

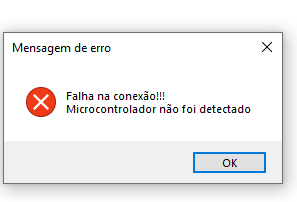
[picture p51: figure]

E o status de conexão ainda permanecerá indicando o estado de desconectado.

Com a conexão feita você poderá navegar pelos os outros 3 menus disponíveis do aplicativo. Caso negativo, ao clicar em qualquer um dos outros 3 menus surgirá a seguinte mensagem de erro:

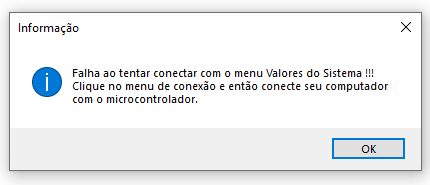
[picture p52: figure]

Portanto, resumindo: Para realizar a conexão do microcontrolador com o pc clique no botão Porta COM e selecione aquela que foi conectado o cabo usb-serial que realiza esta conexão e após isso clique no botão conectar.

Atenção: Ao realizar os passos descritos no parágrafo anterior mas selecionando uma Porta COM diferente daquela onde foi conectado o cabo usb-serial permitirá navegar através dos outros menus, entretanto, todas as funcionalidades destes não funcionarão já que o aplicativo não está de fato conectado ao micro.

Vamos agora descrever o funcionamento dos 3 menus restantes do aplicativo, que são Valores do Sistema, Interface/Display e Estatísticas. Para entrar em cada um deles basta clicar em cima do respectivo nome do menu ou em volta dele, na área onde o cursor tem a forma de uma mão.

Clicando no segundo menu (Valores do Sistema), se terá o seguinte display:

MENU VALORES DO SISTEMA:

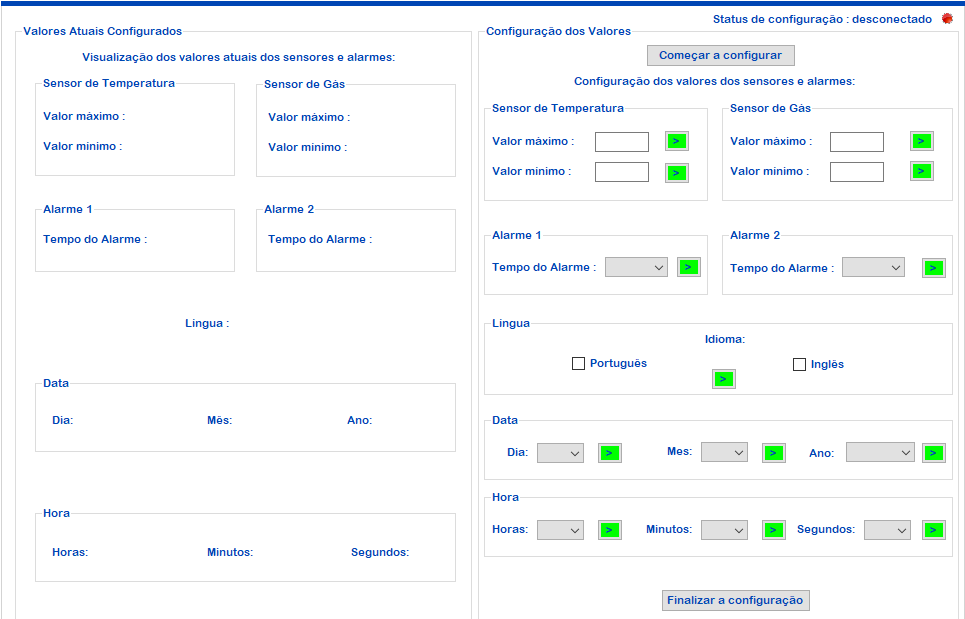
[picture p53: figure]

A principal função deste menu é justamente ter conhecimento dos os valores dos parâmetros do sistema embarcado além de possibilitar a manipulação destes.

Como pode se notar a tela está dividida no meio por 2 grandes sub-menus que são: Valores Atuais Configurados e Configuração dos Valores. O primeiro se trata da visualização dos valores atuais dos parâmetros relativos ao sistema embarcado enquanto que o segundo tem como função a configuração de acordo com o seu desejo destes parâmetros.

Ao clicar no menu os valores no primeiro sub-menu surgirão em um espaço de poucos segundos. Caso isso não aconteça verifique se a conexão foi bem realizada de acordo com todos os requisitos já explicitados anteriormente. Estes valores são atualizados em um espaço de aproximadamente 1 segundo.

Em relação ao segundo sub-menu (Configuração dos Valores) para configurar sucessivamente qualquer um dos parâmetros é necessário primeiramente clicar no botão “Começar a Configurar”. Se isso não for feito, mesmo que confirme os valores sendo enviados, eles não serão de fato recebidos e salvos pelo microcontrolador.

Ao realizar esse clique aparecerá na tela do LCD da placa a mensagem “Config PC” que confirmará que a placa está apta a receber os valores enviados pelo aplicativo, além disso, a placa ficará “congelada” neste estado até que seja apertado o botão de “Finalizar Configuração” ou o botão de reset da própria placa. O motivo para isso é que seja impedido o envio referente a uma mesma variável de dois dispositivos diferentes ao mesmo tempo. Há também o status de configuração, localizado na parte superior direita da tela que serve para indicar se o botão de começar a configurar já foi apertado, e portanto, o aplicativo está apto a mandar valores via serial para o microcontrolador. Quando o botão é apertado, o status ganha a seguinte forma:

Uma vez feito isso, escolha o parâmetro que deseja mudar e faça os seguintes passos:

Caso os parâmetros sejam o valor máximo e mínimo da temperatura e do sensor de gás clique na caixa de texto e digite o valor numérico desejado. Os valores destes parâmetros estão limitados na casa de 3 dígitos da mesma forma definido na placa, ou seja, englobam valores de 0 a 999. Caso seja digitado uma letra ou qualquer outro caractere que não seja um número aparecerá a mensagem de erro a seguir:

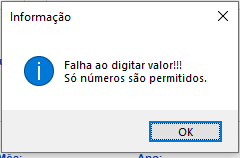
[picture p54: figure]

Digitando apenas números não ocorrerá esse problema. Tendo digitado o valor desejado clique no botão verde seguinte à caixa de texto e aparecerá a seguinte mensagem de confirmação:

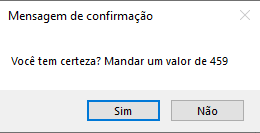
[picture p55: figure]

Onde o valor de 459 foi um exemplo dado.

Caso você tenha certeza de mandar o valor digitado clique em Sim e o valor será mandado ao microcontrolador além de receber a mensagem de sucesso de envio, mostrada a seguir:

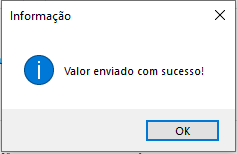
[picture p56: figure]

. Em poucos segundos este valor já será mostrado no primeiro sub-menu de visualização dos parâmetros, como é exemplificado logo abaixo:

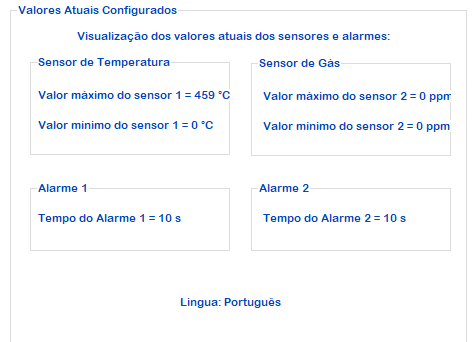
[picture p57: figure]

Além disso, o aplicativo ainda verifica se o valor que está sendo enviado como máximo é de fato maior do que o mínimo e se o valor mínimo enviado é realmente menor do que o máximo para que não haja complicações de leitura inconsequentes. Isso é feito da seguinte forma. Os valores atuais (aqueles que são mostrados na seção de Valores Atuais Configurados) são lidos e então comparados com os valores que estão sendo enviados. Caso a comparação tenha resultado incoerente surge uma mensagem de erro. Caso não, o valor é enviado sem complicações.

O exemplo a seguir exemplifica isso:

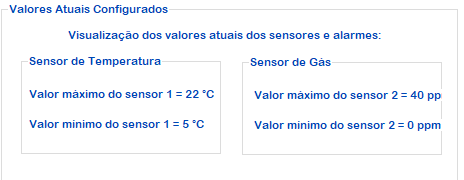
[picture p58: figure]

O valor máximo definido para a temperatura é de 22 C e o mínimo de 5 C.

Uma tentativa de colocar como o valor mínimo 28 acarreta na mensagem:

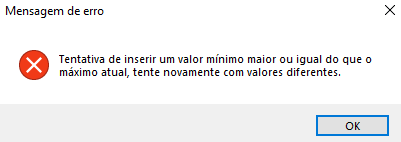
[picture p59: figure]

O caso inverso também se aplica:

O resultado é:

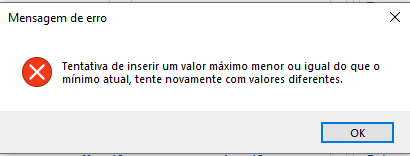
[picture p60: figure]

Em relação aos tempos dos alarmes e aos parâmetros de data e hora, basta clicar na caixa seguinte ao respectivo parâmetro e daí surgirão todos os valores disponíveis para escolha. Pegue aquele que deseja e clique no botão verde seguinte à respectiva caixa de texto. Surgirá novamente a mensagem de confirmação e em caso positivo o valor será mandado sucessivamente ao microcontrolador.

Já com respeito à linguagem clique na caixa de texto da língua desejada e então clique no botão verde logo abaixo seguido de sim na mensagem de confirmação.

Uma vez que você tenha terminado a configuração de todos os parâmetros desejados clique no botão “Finalizar Configuração”. Desta forma, quaisquer valores confirmados no sub-menu não serão enviados ao microcontrolador, a menos que volte a apertar o botão “Começar a configurar”. Além disso, no LCD da placa estará mostrando o estado dos sensores, ou seja, se poderá mais uma vez mexer no sistema da placa por meio dos botões dela. Ao apertar o botão “Finalizar Configuração” o status de configuração voltará ao seu estado original, indicando que o aplicativo não está mais apto a mandar valores para a placa.

MENU INTERFACE/DISPLAY:

Ao clicar no menu interface/display será visto inicialmente na tela:

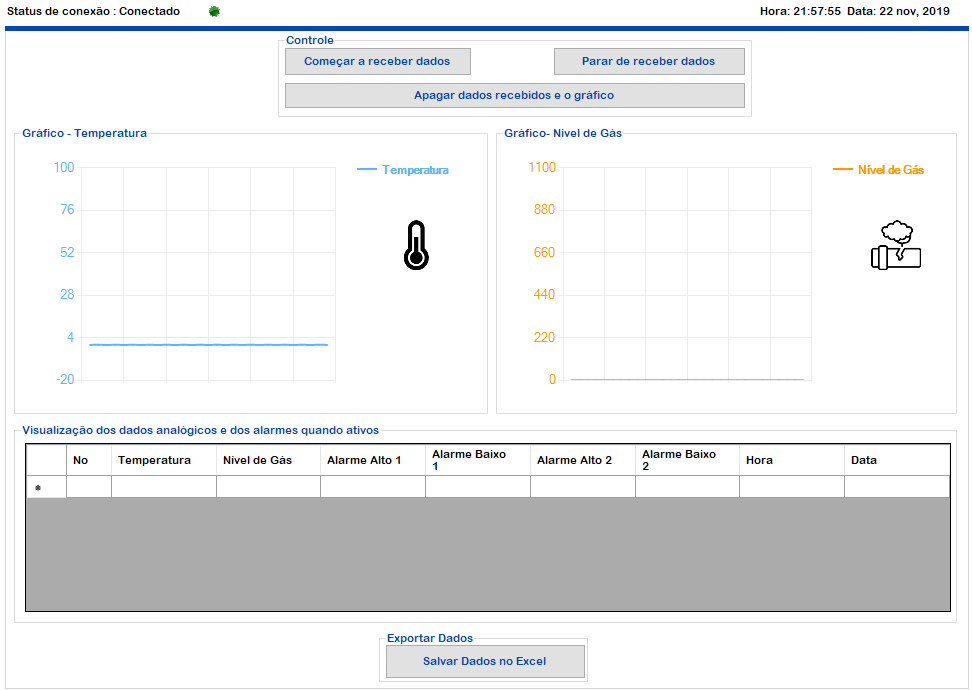
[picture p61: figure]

Têm-se no total 5 seções principais neste menu: Controle, Gráfico-Temperatura, Gráfico-Nível de Gás, Visualização dos dados analógicos e dos alarmes quantos ativos e Salvar Dados no Excel.

Vamos começar pelo primeiro e mais importante: O Controle.

Esta seção possui 3 botões. O clique no botão “Começar a receber dados” como o próprio nome diz faz com que os dados referentes às medições realizadas pelos sensores da placa sejam recebidos pelo aplicativo. A visualização destes valores é feita através dos gráficos do menu (um para o sensor de temperatura e outro relativo ao nível de gás) e pela tabela de valores localizada na seção inferior do menu. Estes valores são recebidos em tempo real e atualizados a cada 1 segundo.

Além dos valores dos sensores têm-se na tabela as colunas Alarme Alto 1, Alarme Baixo 1, Alarme Alto 2 e Alarme Baixo 2. Estes valores dizem respeito a quando o alarme é ativo e detectado pela placa. Em caso positivo o valor será carregado e mostrado em seu valor literal na tabela. Em caso negativo será mostrado como padrão “-“. Os Alarmes Alto e Baixo se referem ao sensor de temperatura e os Alarmes Alto e Baixo 2 ao sensor de gás. Só lembrando que estes alarmes são ativos no momento em que os valores adquiridos pelos sensores saem dos limites definidos pelos parâmetros de valores máximos e mínimos de cada sensor.

Ao clicar no botão “Parar de Receber Dados” simplesmente se parará de mostrar os valores recebidos dos sensores tanto nos gráficos quanto na tabela.

O clique no botão “Apagar Dados Recebidos e Gráfico” basicamente apaga todos os valores carregados na tabela e zera os gráficos.

Por fim, o botão “Salvar Dados no Excel” salva todos os valores carregados na tabela em uma planilha do Excel. Este botão só estará disponível para ser clicado em caso de um clique anterior no botão “Parar de Receber Dados”, ou seja, a tabela não pode estar recebendo dados no momento em que estiver sendo salva no Excel. O processo de salvamento pode demorar algum tempo ainda mais se houver muitos valores adquiridos na tabela. Você pode dar o nome que quiser ao arquivo que será salvo além de escolher como bem quiser o lugar onde ele será guardado.

Um exemplo que mostra o funcionamento do menu quando conectado com a placa e após o clique no botão começar a receber dados é mostrado a seguir:

Gráficos em tempo real:

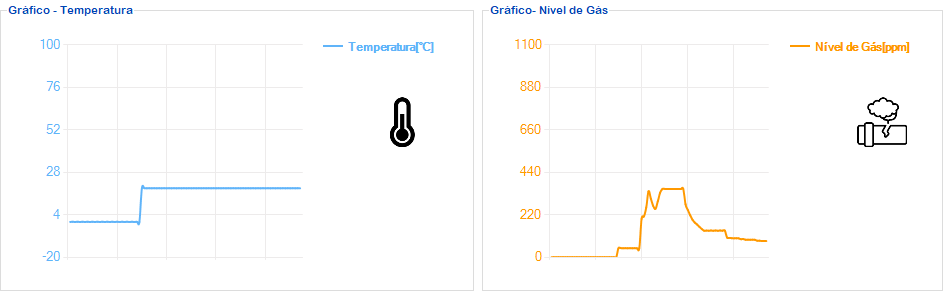
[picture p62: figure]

Tabela de dados:

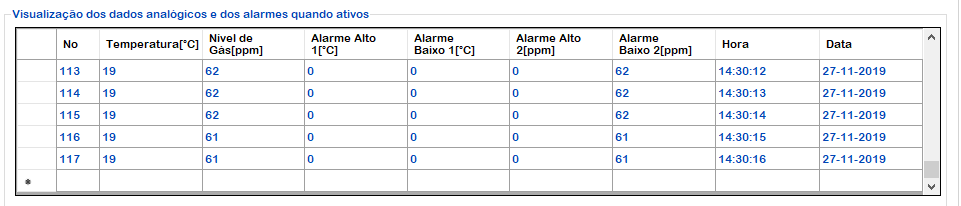
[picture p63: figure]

Arquivo salvo no excel com os dados recebidos na tabela.

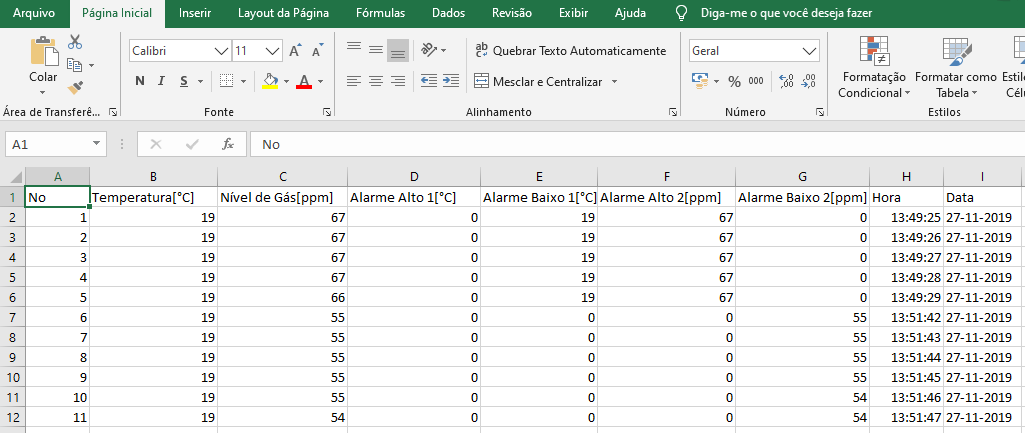
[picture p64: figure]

MENU ESTATÍSTICAS:

Este menu mostra as estatísticas mais relevantes em relação às variáveis presentes no menu Interface/Display, ou seja, os valores de Temperatura, Nível de Gás e dos Alarmes quando ativos.

São mostrados a respeito da temperatura e nível de gás o valor atual, o valor máximo e mínimo adquiridos além do valor médio durante todo o processo de amostragem.

Já com relação aos alarmes, são mostradas todas as variáveis já ditas no parágrafo anterior além do número de ocorrências dos alarmes por segundo, isto é, o número de vezes por segundo em que o respectivo alarme esteve ativo, ou seja, diferente de 0.


Um exemplo deste menu operando, com o aplicativo já conectado com a placa, é mostrado abaixo:


ESTADO DOS ALARMES:

Além dos menus disponíveis no aplicativo há também um grupo de texto localizado na parte inferior aos menus chamado Estado dos Alarmes. Sua função é basicamente informar a quem estiver usando o aplicativo o estado de cada um dos alarmes (ativo ou não) aonde quer que o usuário esteja mexendo. Este texto estará disponível para ser visualizado em todos os menus e indicará com a cor e com o texto o nível do alarme. Se este estiver desativo, será dito que o alarme está desativo e a cor será verde. Se o alarme estiver ativo, será mostrado que ele está de ativo além de mostrar o seu valor atual. Além disso soará um beep a cada segundo para ainda que você esteja mexendo com outra coisa no computador será possível perceber que há um problema com os alarmes. Um exemplo é mostrado a seguir:


DESCONEXÃO DA PLACA:

Quando a placa ou o cabo serial são retirados, fazendo assim com que se interrompa a conexão aparece a seguinte mensagem no aplicativo:


Depois de clicar em ok, você poderá navegar livremente pelos menus do aplicativo, ainda que nenhum dado a mais será recebido. Além disso, os valores atuais são substituídos por uma mensagem de que a conexão está desconectada seguida pelo último valor do parâmetro recebido, como é mostrado abaixo:


Além disso, o status de conexão volta a indicar um estado desconectado.

Ainda que o cabo ou o micro voltem a ser conectados, o aplicativo ainda permanecerá inapto a receber e enviar dados novamente. Para reestabelecer a conexão é necessário voltar ao menu conexão e conectar novamente seguindo os passos já descritos no começo do material.

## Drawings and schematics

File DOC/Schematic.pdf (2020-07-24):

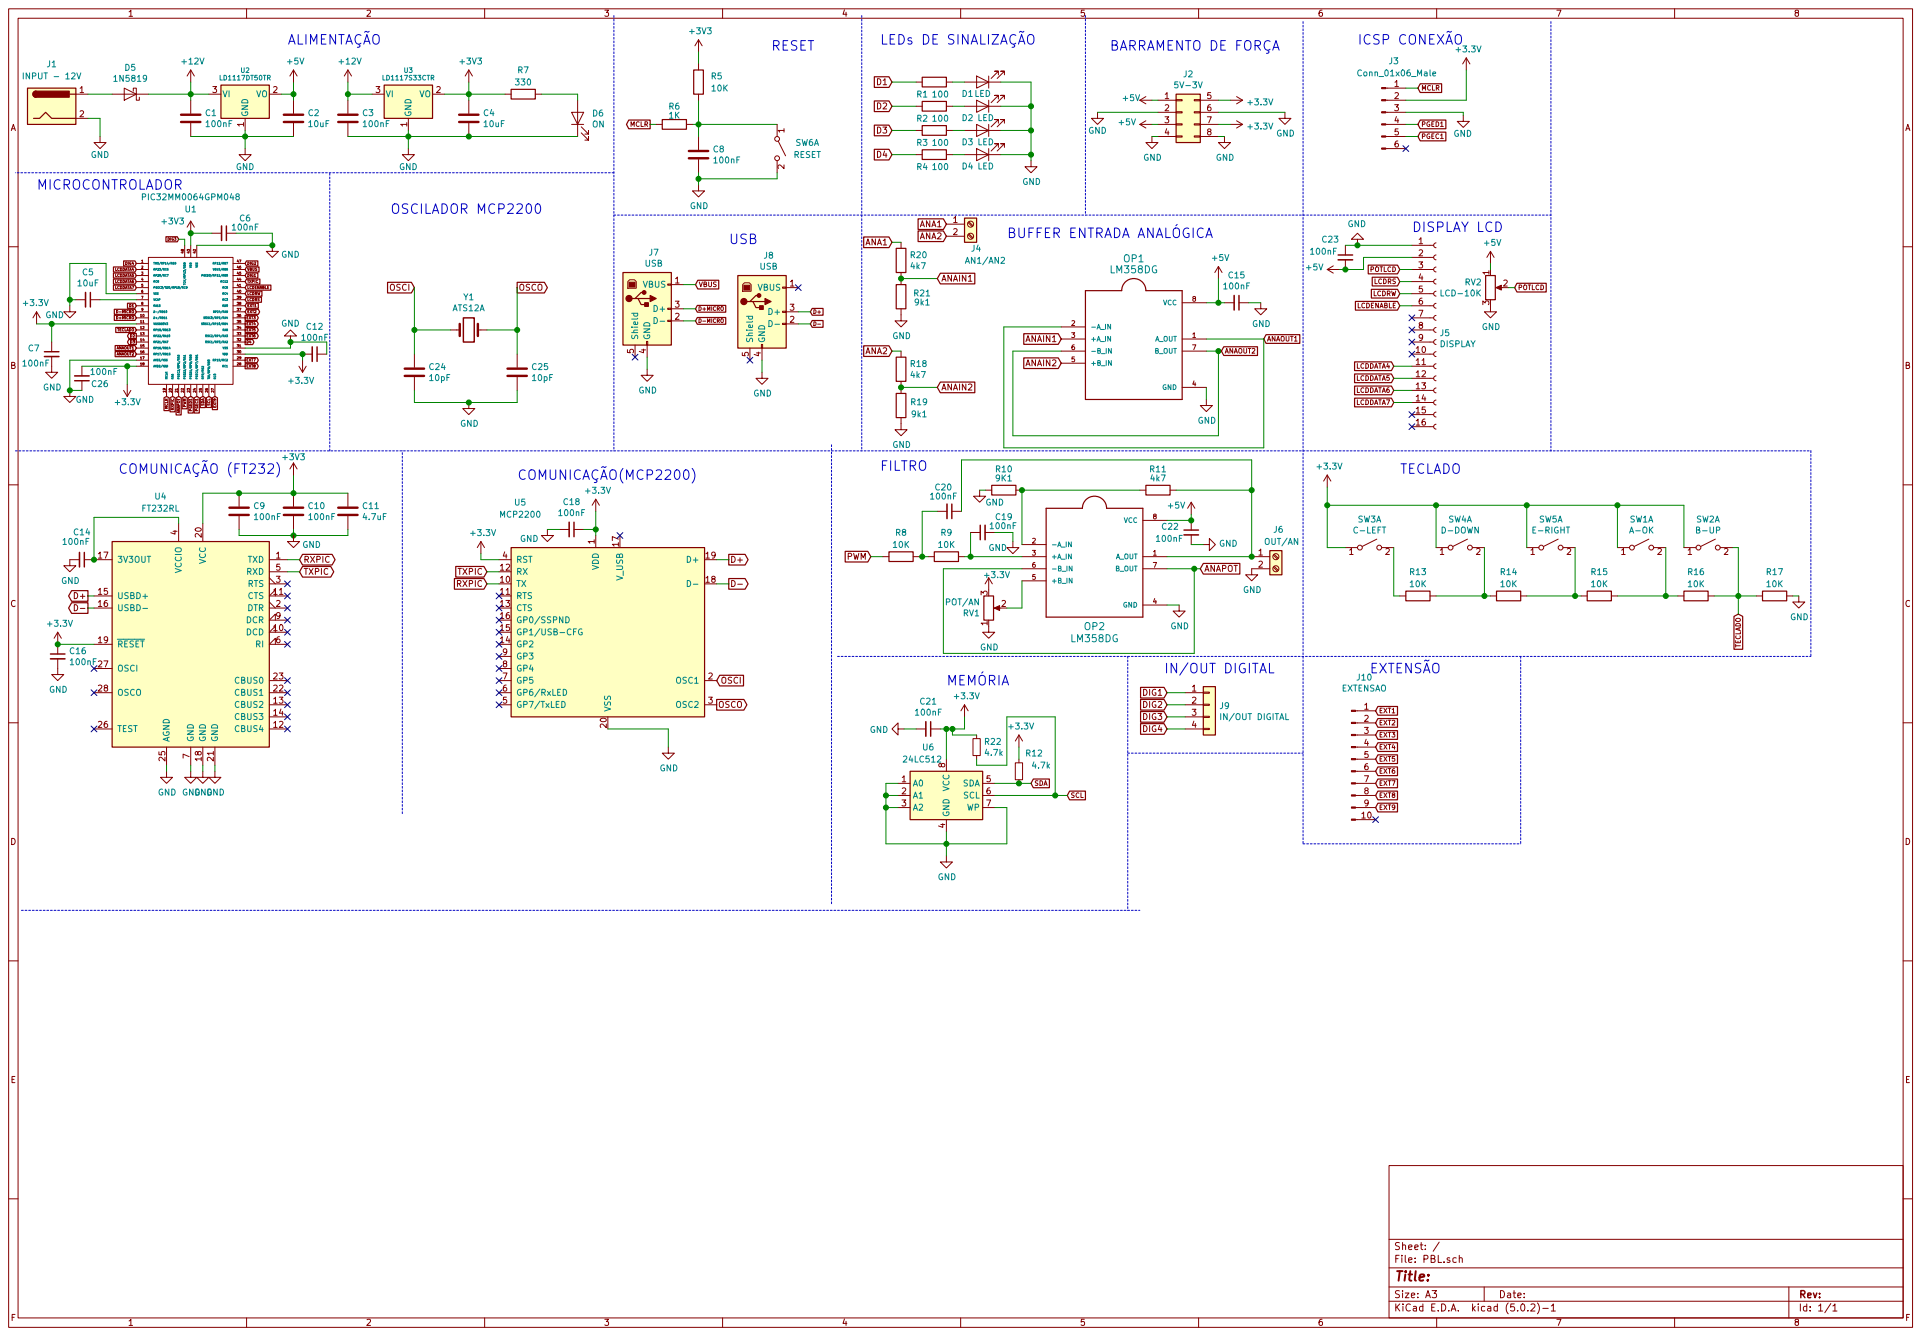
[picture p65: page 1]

100nF GND BUFFER ENTRADA ANALÓGICA

1 TX 10 RTS 11 RX 12 CTS 13 GP2 14 GP1/USB-CFG 15 GP0/SSPND 16 V_USB 17 D- 18 D+ 19 OSC1 2 VSS 20 OSC2 3 RST 4 GP7/TxLED 5 GP6/RxLED 6 GP5 7 GP4 8 GP3 9 U5 MCP2200 COMUNICAÇÃO(MCP2200) RXPIC

4 SDA 5 SCL 6 WP 7 VCC

Id: 1/1 Title: File: PBL.sch Sheet: /

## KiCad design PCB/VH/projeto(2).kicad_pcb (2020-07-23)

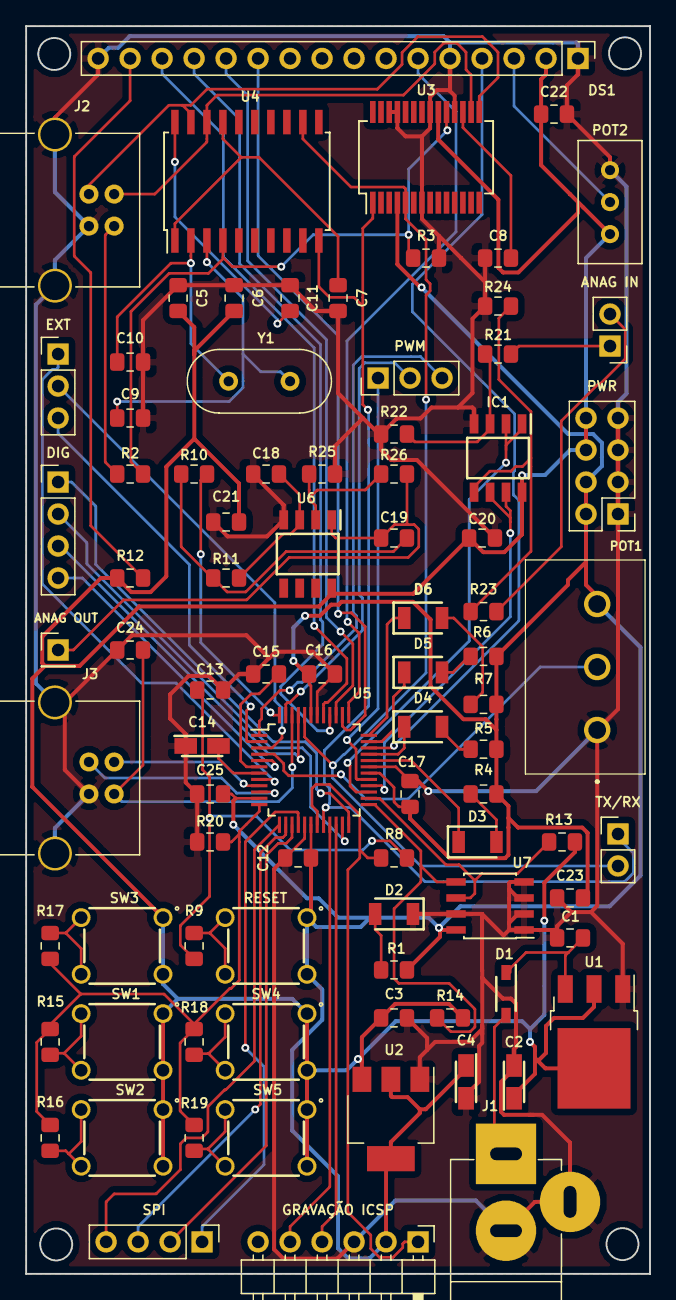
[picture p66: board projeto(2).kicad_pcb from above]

Board: 2 copper layers, 49.5 x 99.1 mm, 87 parts (0 on the bottom side), 77 nets.

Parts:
ANAG IN: Entrada Anag; PinHeader_1x02_P2.54mm_Vertical
ANAG OUT: Saída Anag; PinHeader_1x01_P2.54mm_Vertical
C1, C3, C5, C6, C7, C8, C11, C12, C13, C15, C16, C17, C20, C21, C22, C23, C25: 100nF; C_0805_2012Metric_Pad1.15x1.40mm_HandSolder
C2, C4, C14: 10uF; CAPPM3216X180N
C9, C10: 22pF; C_0805_2012Metric_Pad1.15x1.40mm_HandSolder
C18, C19, C24: 10nF; C_0805_2012Metric_Pad1.15x1.40mm_HandSolder
D1: D_Schottky; SOD3716X145N
D2: LED; LEDC3216X120N
D3, D4, D5, D6: .; LEDC3216X120N
DIG: Digitais; PinHeader_1x04_P2.54mm_Vertical
DS1: JHD162A; Socket_Strip_Straight_1x16_Pitch2.54mm
EXT: EXT; PinHeader_1x03_P2.54mm_Vertical
GRAVAÇÃO ICSP: Gravação; PinHeader_1x06_P2.54mm_Horizontal
IC1: LM358DG; SOIC127P600X175-8N
J1: Jack-DC; JACK_ALIM
J2: USB_B
J3: USB_B2; USB_B
POT1: 10k; P160KN0QD15B10K
POT2: 10k; Potentiometer_Bourns_3296W_Vertical
PWM: PWM; PinHeader_1x03_P2.54mm_Vertical
PWR: PWR; PinHeader_2x04_P2.54mm_Vertical
R1, R4, R5, R6, R7: 330; R_0805_2012Metric_Pad1.15x1.40mm_HandSolder
R2: 4.7k; R_0805_2012Metric_Pad1.15x1.40mm_HandSolder
R3, R9, R13, R14: 10k; R_0805_2012Metric_Pad1.15x1.40mm_HandSolder
R8, R17, R20: 1k; R_0805_2012Metric_Pad1.15x1.40mm_HandSolder
R10, R11: 3.3k; R_0805_2012Metric_Pad1.15x1.40mm_HandSolder
R12, R18, R21, R23: 470; R_0805_2012Metric_Pad1.15x1.40mm_HandSolder
R15: 6.8k; R_0805_2012Metric_Pad1.15x1.40mm_HandSolder
R16: 3,3k; R_0805_2012Metric_Pad1.15x1.40mm_HandSolder
R19: 100; R_0805_2012Metric_Pad1.15x1.40mm_HandSolder
R22, R24: 910; R_0805_2012Metric_Pad1.15x1.40mm_HandSolder
R25: 9,1k; R_0805_2012Metric_Pad1.15x1.40mm_HandSolder
R26: 4,7k; R_0805_2012Metric_Pad1.15x1.40mm_HandSolder
RESET: 1825910-6
SPI: SPI; PinHeader_1x04_P2.54mm_Vertical
SW1, SW2, SW3, SW4, SW5: 1825910-6
TX/RX: Conn_01x02; PinHeader_1x02_P2.54mm_Vertical
U1: LD1117DT50TR; TO-252-3_TabPin2
U2: LD1117S33TR_SOT223; SOT-223-3_TabPin2
U3: FT232RL; SSOP-28_5.3x10.2mm_Pitch0.65mm
U4: MCP2200-I-SO; SOIC-20W_7.5x12.8mm_P1.27mm
U5: PIC/MICRO; TQFP-48_7x7mm_P0.5mm
U6: LM358; SOIC127P600X175-8N
U7: 24LC512; SOIC-8_3.9x4.9mm_P1.27mm
Y1: 12MHz; Crystal_HC49-4H_Vertical

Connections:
/3.3V: C4.1, C12.2, C16.2, C17.2, C23.2, C25.1, GRAVAÇÃO ICSP.2, POT1.3, PWR.2, PWR.4, R1.1, R4.2, R5.2, R6.1, R7.1, RESET.1, RESET.2, U2.2, U3.4, U5.11, U5.18, U5.30, U5.43, U7.8
/5V: C2.1, C3.1, C5.1, C6.1, C20.1, C21.2, C22.1, DS1.2, IC1.8, POT2.3, PWR.6, PWR.8, R12.2, R13.1, R14.1, SW1.1, SW1.2, SW2.1, SW2.2, SW3.1, SW3.2, SW4.1, SW4.2, SW5.1, SW5.2, U1.2, U2.3, U3.20, U6.8
/Comunicação/3.3v: C7.1, U4.1, U4.17
/Comunicação/RST: R2.2, R3.1, U3.19, U4.4
/Comunicação/RX: TX/RX.2, U3.5, U4.12, U5.44
/Interface/EN1: ANAG IN.1, R21.1
/Interface/EN2: ANAG IN.2, R23.1
/Interface/IN1: IC1.1, IC1.2, U5.27
/Interface/IN2: IC1.6, IC1.7, U5.28
/Interface/IN3: POT1.2, U5.4
/Interface/PWM: R10.2, U5.48
/Interface/SaidaANA: ANAG OUT.1, C19.1, R26.1, U6.1
/Periféricos/E: DS1.6, U5.37
/Periféricos/LCD1: DS1.11, U5.38
/Periféricos/LCD2: DS1.12, U5.39
/Periféricos/LCD3: DS1.13, U5.40
/Periféricos/LCD4: DS1.14, U5.41
/Periféricos/RS: DS1.4, U5.34
/Periféricos/SCL: R13.2, U5.26, U7.6
/Periféricos/SDA: R14.2, U5.25, U7.5
/Periféricos/TECLADO: R15.2, R16.2, R17.2, R18.2, R19.2, R20.2, U5.12
/microcontrolador/MCLR: GRAVAÇÃO ICSP.1, R8.2, U5.19
/microcontrolador/PGEC1: DIG.1, U5.24
/microcontrolador/PGEC2: GRAVAÇÃO ICSP.5, U5.21
/microcontrolador/PGEC3: DIG.4, U5.5
/microcontrolador/PGED1: DIG.2, U5.23
/microcontrolador/PGED2: GRAVAÇÃO ICSP.4, U5.22
/microcontrolador/PGED3: DIG.3, U5.45
/microcontrolador/PWM2: PWM.3, U5.1
/microcontrolador/PWM3: PWM.2, U5.47
/microcontrolador/PWM4: PWM.1, U5.29
/microcontrolador/RX: TX/RX.1, U3.1, U4.10, U5.20
GND: C1.2, C2.2, C3.2, C4.2, C5.2, C6.2, C7.2, C8.2, C9.2, C10.1, C11.1, C12.1, C13.2, C14.1, C15.2, C16.1, C17.1, C18.1, C20.2, C21.1, C22.2, C23.1, C24.2, C25.2, D2.1, DS1.1, DS1.5, DS1.16, GRAVAÇÃO ICSP.3, IC1.4, J1.2, J1.3, J2.4, J2.5, J3.4, J3.5, POT1.1, POT2.1, PWR.1, PWR.3, PWR.5, PWR.7, R3.2, R20.1, R22.2, R24.2, R25.2, U1.1, U2.1, U3.7, U3.18, U3.21, U3.25, U3.26, U5.17, U5.31, U5.42, U6.4, U7.1, U7.2, U7.3, U7.4, U7.7
unnamed: C1.1, D1.1, U1.3
unnamed: C8.1, U3.17
unnamed: C9.1, U4.3, Y1.1
unnamed: C10.2, U4.2, Y1.2
unnamed: C11.2, U4.20
unnamed: C13.1, R8.1, R9.1
unnamed: C14.2, U5.7
unnamed: C15.1, U5.6
unnamed: C18.2, R11.1, U6.3
unnamed: C19.2, R10.1, R11.2
unnamed: C24.1, J3.1, U5.46
unnamed: D1.2, J1.1
unnamed: D2.2, R1.2
unnamed: D3.1, U5.32
unnamed: D3.2, R4.1
unnamed: D4.1, U5.33
unnamed: D4.2, R5.1
unnamed: D5.1, U5.35
unnamed: D5.2, R6.2
unnamed: D6.1, U5.36
unnamed: D6.2, R7.2
unnamed: DS1.3, POT2.2
unnamed: DS1.15, R12.1
unnamed: IC1.3, R21.2, R22.1
unnamed: IC1.5, R23.2, R24.1
unnamed: J2.1, R2.1
unnamed: J2.2, U3.16, U4.18
unnamed: J2.3, U3.15, U4.19
unnamed: J3.2, U5.9
unnamed: J3.3, U5.10
unnamed: SPI.1, U5.16
unnamed: SPI.2, U5.15
unnamed: SPI.3, U5.14
unnamed: SPI.4, U5.13
unnamed: EXT.1, U5.8
unnamed: EXT.2, U5.3
unnamed: EXT.3, U5.2
unnamed: R9.2, RESET.3, RESET.4
unnamed: R15.1, SW1.3, SW1.4
unnamed: R16.1, SW2.3, SW2.4
unnamed: R17.1, SW3.3, SW3.4
unnamed: R18.1, SW4.3, SW4.4
unnamed: R19.1, SW5.3, SW5.4
unnamed: R25.1, R26.2, U6.2

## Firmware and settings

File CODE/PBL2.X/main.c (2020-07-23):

/**
  Generated main.c file from MPLAB Code Configurator

  @Company
    Microchip Technology Inc.

  @File Name
    main.c

  @Summary
    This is the generated main.c using PIC24 / dsPIC33 / PIC32MM MCUs.

  @Description
    This source file provides main entry point for system initialization and application code development.
    Generation Information :
        Product Revision  :  PIC24 / dsPIC33 / PIC32MM MCUs - 1.125.1
        Device            :  PIC32MM0064GPM048
    The generated drivers are tested against the following:
        Compiler          :  XC16 v1.36B
        MPLAB 	          :  MPLAB X v5.20
 */

/*
    (c) 2016 Microchip Technology Inc. and its subsidiaries. You may use this
    software and any derivatives exclusively with Microchip products.

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
    IN NO EVENT WILL MICROCHIP BE LIABLE FOR ANY INDIRECT, SPECIAL, PUNITIVE,
    INCIDENTAL OR CONSEQUENTIAL LOSS, DAMAGE, COST OR EXPENSE OF ANY KIND
    WHATSOEVER RELATED TO THE SOFTWARE, HOWEVER CAUSED, EVEN IF MICROCHIP HAS
    BEEN ADVISED OF THE POSSIBILITY OR THE DAMAGES ARE FORESEEABLE. TO THE
    FULLEST EXTENT ALLOWED BY LAW, MICROCHIP'S TOTAL LIABILITY ON ALL CLAIMS IN
    ANY WAY RELATED TO THIS SOFTWARE WILL NOT EXCEED THE AMOUNT OF FEES, IF ANY,
    THAT YOU HAVE PAID DIRECTLY TO MICROCHIP FOR THIS SOFTWARE.

    MICROCHIP PROVIDES THIS SOFTWARE CONDITIONALLY UPON YOUR ACCEPTANCE OF THESE
    TERMS.
 */

/**
  Section: Included Files
 */
#include "mcc_generated_files/system.h"
#include "mcc_generated_files/pin_manager.h"
#include "mcc_generated_files/rtcc.h"
#include "mcc_generated_files/ext_int.h"
#include "mcc_generated_files/tmr1.h"
#include "mcc_generated_files/mccp1_compare.h"
#include "LCD_1.h"
#include "lm35.h"
#include "dht22.h"
#include "memoria_i2c.h"
#include "mcc_generated_files/uart1.h"
#include <stdio.h>

#include "adc.h"
#include "alarme.h"
#include "keypad.h"
#include "RecebeSerial.h"
#include "event.h"
#include "var.h"
#include "stateMachine.h"
#include "output.h"
#include "relogio.h"
#include "calendario.h"
#include "EnviaSerial.h"

#define BitSet(arg,bit) ((arg) |= (1<<bit))
#define BitClr(arg,bit) ((arg) &= ~(1<<bit)) 
#define BitFlp(arg,bit) ((arg) ^= (1<<bit)) 
#define BitTst(arg,bit) ((arg) & (1<<bit)) 

/*
                         Main application
 */
    void myTimer1ISR(void){
        Alarme1Tst();
        Alarme2Tst();
        TMR1_GetElapsedThenClear();
}
void main(void) {
    unsigned int t = 0;
    int valor_1M,valor_1m,valor_2M,valor_2m;
    int x;
    temp = 0;
    //init das bibliotecas
    SYSTEM_Initialize();
    TMR1_SetInterruptHandler(myTimer1ISR);
    eventInit();
    lcdInit();
    lcdClear();
    lcdInit();
    varInit();
    eventInit();
    outputInit();
    lcdInit();
    smInit();
    for (;;) {
        
         MCCP1_COMPARE_Start();
        // DelayMiliS(1000);
        //temperatura_LM35();
        //valor_1M = getV1M();
        //valor_1m = getV1m();
        //valor_2M = getV2M();
        //valor1_2m = getV2m();
        //printf("valor alarme alto 1: %d\r\n",valor_1M);
        //printf("valor alarme baixo 1: %d\r\n",valor_1m);
        //printf("valor alarme alto 2: %d\r\n",valor_2M);
        //printf("valor alarme baixo 2: %d\r\n",valor_2M);
               
        //  buzzer_SetHigh();
        //  DelayMiliS(100);
        //  buzzer_SetLow();
        // gas_sensor();
        //adcRead_Pot();
        // x = getV2M();
        //printf("%d\n", x);
        //  Envia_Valores_Serial();
        //Recebe_Valores_Serial();
        smLoop();
    }
}

/**
 End of File
 */

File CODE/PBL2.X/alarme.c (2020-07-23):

#include "event.h"
#include "adc.h"
#include "var.h"
#include "memoria_i2c.h"
#include "stateMachine.h"
#include "relogio.h"
#include "calendario.h"

// essa biblioteca é responsavel por testar os valores do alarme e ativarem caso algo aconteça
//e tambem salvar os dados de quando o alarme aconteceu

void Alarme1Tst(void) {
    if (adcRead1() > getV1M()) {
        setA1(adcRead1());
        setDd1(rtcGetDay());
        setDm1(rtcGetMonth());
        setDa1(rtcGetYear());
        setHh1(rtcGetHours());
        setHm1(rtcGetMinutes());
        setHs1(rtcGetSeconds());
        setState(STATE_1ATIVO);
    }
    if (adcRead1() < getV1m()) {
        setA1(adcRead1());
        setDd1(rtcGetDay());
        setDm1(rtcGetMonth());
        setDa1(rtcGetYear());
        setHh1(rtcGetHours());
        setHm1(rtcGetMinutes());
        setHs1(rtcGetSeconds());
        setState(STATE_1ATIVO);
    }
}

void Alarme2Tst(void) {
    if (adcRead2() > getV2M()) {
        setA2(adcRead2());
        setDd2(rtcGetDay());
        setDm2(rtcGetMonth());
        setDa2(rtcGetYear());
        setHh2(rtcGetHours());
        setHm2(rtcGetMinutes());
        setHs2(rtcGetSeconds());
        setState(STATE_2ATIVO);
    }
    if (adcRead2() < getV2m()) {
        setA2(adcRead2());
        setDd2(rtcGetDay());
        setDm2(rtcGetMonth());
        setDa2(rtcGetYear());
        setHh2(rtcGetHours());
        setHm2(rtcGetMinutes());
        setHs2(rtcGetSeconds());
        setState(STATE_2ATIVO);
    }
}
